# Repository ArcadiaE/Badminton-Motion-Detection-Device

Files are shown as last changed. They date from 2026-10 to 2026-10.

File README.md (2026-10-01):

# Wearable Device for Badminton Motion Detection

A wrist-worn device that recognises badminton strokes in real time and replies with coaching-style feedback. Built as my Part III individual project (undergraduate dissertation) at the University of Southampton, 2024–25. The full dissertation is in [`docs/Final_Report.pdf`](docs/Final_Report.pdf).

The device streams motion and physiological data over Bluetooth Low Energy. A support vector machine classifies four stroke types — forehand, backhand, slice and smash — at **77.37%** test accuracy (macro-averaged F1 = 0.76), up from 53.91% before the feature set was expanded from 10 to 16 dimensions. Given the single-IMU setup, four-class random guessing sits at 25%. Recognised strokes are passed to the ChatGPT API (GPT-4o), which generates personalised coaching feedback shown in a local Flask web app.

## Hardware

The electronics are packaged as a wristwatch with a 3D-printed case.

- **Microcontroller:** Arduino Nano 33 BLE Sense Rev2
- **IMU:** BMI270 + BMM150 (on-board, nine-axis)
- **Biosensor:** MAX30102 heart-rate and SpO2 module
- **Power:** 3.7 V 350 mAh LiPo battery, TP4056-based charging/management
- **Enclosure:** 3D-printed ([`3D_Model/3D.stl`](3D_Model/3D.stl), [`Enclosure/c1.stl`](Enclosure/c1.stl)); PCB layout in [`PCB/yuanlitu.brd`](PCB/yuanlitu.brd)

## Repository structure

- `Hardware/` — final embedded firmware (Arduino/C++): sensor initialisation, continuous sampling, filtering, differential and peak extraction, BLE broadcasting.
- `Data_Process/Matlab/` — MATLAB scripts for BLE data collection and CSV storage, plus the recorded sessions.
- `Data_Process/modelTrain/` — Jupyter-based SVM training, the trained models (`model/*.pkl`), the labelled stroke dataset (`BM_datas/`), and the Python inference script with the Flask feedback app (`templates/`).
- `Data_Process/python/` — earlier Python BLE capture prototype.
- `docs/` — the final dissertation.

## Dependencies

- **Arduino:** [ArduinoBLE](https://github.com/arduino-libraries/ArduinoBLE), [Arduino_BMI270_BMM150](https://github.com/arduino-libraries/Arduino_BMI270_BMM150), [SparkFun MAX3010x Sensor Library](https://github.com/sparkfun/SparkFun_MAX3010x_Sensor_Library), Madgwick.
- **MATLAB:** BLE toolbox (data collection).
- **Python 3.x:**
  ```bash
  pip install pandas scikit-learn joblib bleak flask openai
  ```

## Workflow

1. **Data acquisition** — the IMU streams tri-axial motion data over BLE; MATLAB scripts record sessions to CSV.
2. **Training** — the SVM is trained on the labelled dataset in a Jupyter notebook; the model, scaler and label encoder are exported with joblib.
3. **Inference** — a Python script receives live data and classifies the stroke with the trained model.
4. **Feedback** — the recognised stroke is sent to the ChatGPT API, and the generated coaching feedback is served in a Flask web interface.

## Author

**Yike Zhang**
School of Electronics and Computer Science, University of Southampton

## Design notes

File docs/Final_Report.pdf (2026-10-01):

# University of Southampton

# Faculty of Engineering and Physical Sciences

# School of Electronics and Computer Science

### Yike Zhang, yz50u22

### 21st April 2025

# Wearable Device for Badminton Motion Detection

### Project supervisor: Doctor Alex Weddell

### Examiner: Doctor Dimitra Georgiadou

### A project report submitted for the

### award of Beng Electrical and Electronic Engineering

### University of Southampton

### ABSTRACT

### FACULTY OF ENGINEERING AND PHYSICAL SCIENCES

### SCHOOL OF ELECTRONICS AND COMPUTER SCIENCE

By: Yike Zhang

Today, badminton motion analysis systems incorporating wearable sensors and machine learn-

ing models allow professional athletes to receive expert guidance more easily, while badminton

motion analysis systems incorporating wearable sensors and machine learning models have

enabled professional athletes to receive expert guidance more easily, existing systems often

remain too costly, bulky, or technically complex for amateur users, limiting their accessibil-

ity and daily usability. Amateur players would benefit more from a smaller, more convenient,

easier-to-understand, and more affordable wearable device. This project aims to design and

implement a wearable device focused on real-time detection of badminton stroke movements,

may facilitate improved access to expert-level guidance by replicating aspects of professional

systems in a more accessible form. The device can collect motion and physiological data,

which are transmitted to a mobile device for analysis via a Bluetooth Low Energy (BLE) mod-

ule. The project encompasses hardware design, data acquisition, signal processing, and the

development of machine learning-based action classification algorithms. The project has com-

pleted hardware coding, BLE communication initialisation, and filtering algorithm implemen-

tation. Beyond these technical completions, a functional prototype was successfully deployed

and tested in real-world scenarios with badminton club participants. The action classification

reached 77.37% accuracy for badminton strokes such as forehand, backhand, and smash. Ad-

ditionally, the system was able to generate real-time, personalised coaching feedback through

an integrated web interface using the ChatGPT API.

Statement of Originality

- I have read and understood the ECS Academic Integrity information and the University’s Academic Integrity Guidance for Students.
- I am aware that failure to act in accordance with the Regulations Governing Academic Integrity may lead to the imposition of penalties which, for the most serious cases, may include termination of programme.
- I consent to the University copying and distributing any or all of my work in any form and using third parties (who may be based outside the EU/EEA) to verify whether my work contains plagiarised material, and for quality assurance purposes.

I have acknowledged all sources, and identified any content taken from elsewhere.

I have acknowledged all sources in the report and clearly cited any content, figures, or ideas taken or adapted from external references.

I have used external resources.

The project uses the ArduinoBLE library by Arduino to implement Bluetooth Low Energy communication functions, and the SparkFun MAX3010x Sensor Library (version 1.0.5) for heart rate and SpO₂ signal acquisition and processing. Official Arduino tutorials for the Nano 33 BLE Sense Rev2 board and BLE device-to-device communication were referenced during sensor initialization and BLE service configuration. The OpenAI ChatGPT API (gpt-4o) was used to generate personalised coaching feedback based on recognised motion data. Additionally, Python libraries including pandas, scikit-learn, and joblib were used for machine learning model training, evaluation, and deployment, while the MATLAB BLE toolbox was employed for real-time data collection and CSV logging.

I did all the work myself, or with my allocated group, and have not helped anyone else.

I carried out all work myself, including hardware implementation, data acquisition, and software development, and did not help any other individual or group with their work.

The material in the report is genuine, and I have included all my data/code/designs.

The material in the report is genuine, and I have included all source code, raw and processed data, and hardware design information necessary to reproduce the results.

I have not submitted any part of this work for another assessment.

I confirm that no part of this work has been submitted for any other assessment, either within or outside the University

My work did not involve human participants, their cells, or animals; it only involved collecting motion data.

Approval was obtained from the University of Southampton Ethics and Research Governance committee (Reference Number: ERGO/FEPS/79094). All procedures were conducted following ethical guidelines, and informed consent was obtained from all participants.

## Contents

List of Figures | 6
List of Symbols | 7
1 Introduction | 8
2 Theoretical Background | 9
3 System Overview | 15
4 System Implementation | 20
5 System Testing, Performance, and Feedback | 27
6 Project Management | 35

7 Conclusion and Future Work | 38
Bibliography | 40
Appendix | 43
A Formulas | 43
B BLE UUID Table | 43
C Sensor Specifications | 44
D Ethics Approval Forms | 45
E Code Examples | 47

## List of Figures

1 | Example of Euler Angles reproduced from [11] | 13
2 | Overview of the Integrated Device | 17
3 | Software Architecture Overview | 19
4 | Code Implementation of I2C Scanner | 20
5 | Technical Drawing of Device Design | 23
6 | An earlier version of the design | 24
7 | When the device is initialised, the information printed by the Serial Monitor . . 28
8 | Outputs on Mobile APP LightBlue | 28
9 | An example of Collected Data | 29
10 | Training Evaluation of Trained Model of Simple Motions | 29
11 | When the device operates properly | 29
12 | Training outcome of the initial Algorithm | 30
13 | Training outcome of Final Algorithm | 31
14 | Code of API Testing Program | 32
15 | API Testing Outcome | 32
16 | UI of Localhost Website | 33
17 | Example of Forehand | 34
18 | Initial Gantt Chart | 36
19 | Fianl Gantt Chart | 37
20 | Pin layout of Arduino Nano 33 BLE Sense Rev2, reproduced form [9] | 44
21 | System Diagram of MAX30102, reproduced form [22] | 44
22 | Signed SOP Form | 45
23 | Ethics Approval Submissions | 45
24 | Ethics Application Form | 46
25 | Code example of Reading Data | 47
26 | Code example of Establish BLE Connection | 48
27 | Code example of Heartrate and SpO2 Algorithm | 48
28 | Peak Count Algorithm | 49
29 | The function for Connecting and Data Storage | 49
30 | Code example of Data Processing Progress in Pyhton | 50

31 | Code example of UI | 51
32 | Code example of Extended 16 Features | 52

## List of Symbols

IMU | Inertial Measurement Unit
Hz | Hertz (Unit of Frequency)
SpO2 | blood oxygen saturation

KNN K-Nearest Neighbor Algorithm

SV M | Support vector machine
BLE | Bluetooth low energy
ϕ | Roll (Used in this report)
θ | Pitch (Used in this report)
ψ | Yaw (Used in this report)

## 1. Introduction

### 1.1. Motivation

Modern professional badminton players can often benefit from the guidance provided by expert

coaches. With the integration of wearable sensors and machine learning technologies, advanced

badminton motion analysis systems are increasingly being adopted for training and gameplay.

However, for amateur badminton players, participating in periodic badminton courses offered

by clubs or other organisations often comes with challenges, such as the time it takes to partic-

ipate and the distances between home and clubs. Purchasing and using professional badminton

analysis systems can be expensive or overly complicated. So, designing a wearable device that

is cost-effective, portable, and user-friendly would enable users to effortlessly monitor their

performance data and receive personalised recommendations, helping them improve their tech-

niques. Furthermore, it enhances their enjoyment of the sport and reduces the risk of injuries

during play.

### 1.2. Project Objectives

The core objective of this project is to develop a wearable device and miniaturised device

based on a single sensor node for badminton stroke recognition, targeting amateur sports en-

thusiasts to enhance their real-time motion feedback and performance evaluation capabilities.

The system aims to capture users’ movement and physiological signals to recognize different

badminton strokes and provide real-time personalised feedback to amateur players. It is de-

signed to be lightweight, wearable, and capable of unobtrusive data acquisition during play.

Captured data should be processed efficiently to classify stroke types and generate actionable

improvement suggestions. The system must offer reliable operation, intuitive user interaction,

and the ability to support continuous skill development without needing professional supervi-

sion. Initially, data was collected from experienced badminton players through self-conducted

recording sessions to train a stroke classification model. Subsequently, when amateur bad-

minton players use the device, their real-time motion data will be compared against the trained

model. The comparison results will then be input into a large-scale artificial intelligence sys-

tem to generate personalized recommendations, with both the collected data and the generated

feedback visualized through platforms such as web interfaces.

### 1.3. Scope and Deliverables

This project covers hardware assembly, embedded development, data communication, web in-

terface construction, data acquisition programming, and data structure design. The system

components include the Arduino Nano 33 BLE Sense Rev2, the MAX30102 module, a 3D-

printed enclosure, and wearable mounting structures. The development work will be limited to

firmware-level sensor drivers, data acquisition programs, attitude estimation algorithms, BLE

characteristic configuration, a front-end display interface based on Flask, and MATLAB or

Python scripts for data reception and storage. The project deliverables include a functional pro-

totype of the sensor hardware, a set of host-side scripts supporting BLE interaction, a collection

of data samples for training classification models, and a basic web-based data visualisation in-

terface. The data collected during the project will be limited to the three-axis motion data of

the wrist. Physiological data collected by the MAX30102 will not be stored and will only serve

as a reference for users. All data collected in this project will be anonymous, containing no

identifiers that can link the data to individual participants, and the project has received ethical

approval from the Ethics Committee of the University of Southampton.

## 2. Theoretical Background

### 2.1. Motion Detection Techniques for Sports

### 2.1.1 Existing Projects

In sports motion analysis, wearable IMU(Inertial Measurement Unit) sensors have become a

prominent method for accurately identifying and classifying motion patterns. For instance,

Camomilla et al. [1]. During their research, they used IMU, which includes an accelerometer,

a gyroscope, and a Magnetic sensor, and analysed over 37 sports. They proved that the IMU

can be used to identify and classify sports. A particularly relevant study by Cutti et al. (2008)

proposed a calibration procedure for upper limb joint kinematics using wearable magnetic and

inertial measurement units based on bony landmark identification [2]. Similarly, Lebel et al.

(2018) applied wearable IMUs to running gait analysis, enhancing the understanding of biome-

chanics and the risk factors for injuries [3].

In badminton motion analysis, accurately identifying and classifying stroke actions is a critical

research area. Wang et al. (2016) proposed a method for badminton stroke recognition based

on Body Sensor Networks (BSNs) [4]. In their study, multiple IMU sensors were placed at

key locations on the athlete’s body, including the wrist, arm, and legs, to form a comprehen-

sive network for capturing motion data. Wang et al. adopted a multi-sensor setup to obtain

comprehensive motion data. While Camomilla et al. emphasized the broad applicability of

IMUs across sports, their work lacked domain-specific optimizations, limiting direct transfer-

ability to badminton. Cutti et al.’s approach offered precise limb joint calibration, but required

cumbersome wired systems unsuitable for mobile use. Lebel et al. focused on gait analy-

sis, which differs structurally from upper limb dynamics in racket sports. In contrast, Wang

et al.’s multi-sensor BSN system offered richer motion data but increased system complexity,

cost, and wearing discomfort. It should also be noted that Wang et al. evaluated the recogni-

tion performance of individual sensor nodes. Their results showed that the wrist sensor node

alone achieved the highest individual accuracy among the tested locations, reaching an aver-

age recognition accuracy of 81.63%. This suggests that, while a multi-node system enhances

overall robustness, a well-placed single sensor (such as on the dominant wrist) can still de-

liver relatively high accuracy, particularly when paired with appropriate signal processing and

feature extraction techniques.

### 2.1.2 Hardware Selections

In the study conducted by Cutti et al., a sensor named MT9B was employed, which comprised

a 3D accelerometer, a 3D gyroscope, and a 3D magnetometer, operating at a fixed sampling

rate of 100 Hz. This sensor required a wired connection to a computer and did not support

wireless transmission. In the study by Lebel et al., Attitude and Heading Reference Systems

(AHRS) were utilized to analyze motion performance, comparing systems such as the Xsens

MTx, APDM Opal, and Inertial Labs OSv3.

In the research by Wang et al., each sensor node comprised a triaxial accelerometer (ADXL326),

a single-axis gyroscope (LY550), and a biaxial gyroscope (LPR550). As these sensors lacked

integrated Bluetooth functionality, ZigBee modules were implemented to configure the sensor

nodes, and a wireless receiver module was connected to the computer for data acquisition.

In this project, the focus is on developing a miniaturized device based on a single sensor node;

therefore, sensor systems similar to those used by Cutti et al. and Lebel et al. will not be

considered. Instead, designs akin to that proposed by Wang et al., involving a microcontroller

with integrated Bluetooth functionality combined with an additional IMU module, are consid-

ered more appropriate. Several candidate solutions are summarized in Table 1. Among the

compared hardware options, professional-grade solutions like Xsens or Shimmer offer high

accuracy and sampling rates, but their prohibitive cost and setup complexity render them im-

practical for casual or amateur users. Raspberry Pi and ESP32 platforms offer programmability

and wireless communication but require additional IMU modules, increasing power consump-

tion and form factor, which may hinder integration in a wearable form. Arduino Nano 33 BLE

Sense Rev2, although limited in memory and requiring manual programming of BLE commu-

nication, provides a compact and integrated platform combining BLE and IMU in one unit.

This balance of cost, size, and functionality makes it the most suitable choice for this project’s

lightweight, wrist-mounted wearable application.

Option | Advantages | Disadvantages | Cost (£)
1. Raspberry Pi 4B + Ex-ternal IMU Module[6] | • User-friendly • Supports MicroPython and C/C++ programming. | • Requires an external sensor module, increasing size and power consumption. • Requires an additional wireless module. | • £60+
2. ESP32 Series De-velopment Board + Ex-ternal IMU Module[5] | • Built-in Wi-Fi and BLE. • Smaller size | • Also requires an external IMU module. • Higher power consump-tion; not conducive to portable sports equipment applications. | • £35+
3. Pro-fessional Sports Sensor Equip-ment (e.g., Xsens[7], Shimmer[8]) | • High precision and high sampling rate; professional-level motion capture performance. | • Expensive. For example, it costs C430 to purchase a Shimmer IMU unit. • Complex equipment. | • £370+
4. Arduino Nano 33 BLE Sense rev2[9] | • High Integration, the BLE and IMU modules are inte-grated on board. • Low Power Consumption. | • 256 KB of SRAM and 1 MB of flash limit the size of programs. • Relatively harder to pro-gram: i.e. Algorithms and BLE need to be established by programming. | • £50

Table 1: Comparison of Hardware Options

### 2.2. Attitude Estimation Algorithms

Attitude estimation involves determining an object’s orientation and rotational state in space. In

three-dimensional space, Euler angles can describe the orientation of a rigid body that requires

three independent angular parameters, which consist of roll (ϕ), pitch (θ), and yaw (ψ). Roll

refers to the rotation around the X-axis and represents the left or right tilt of the object. Pitch

refers to the rotation around the Y-axis and indicates the forward or backward tilt. Yaw refers

to the rotation around the Z-axis and describes the direction of the object within the horizontal

plane[10]. An example of Euler angles is shown in Fig.1.

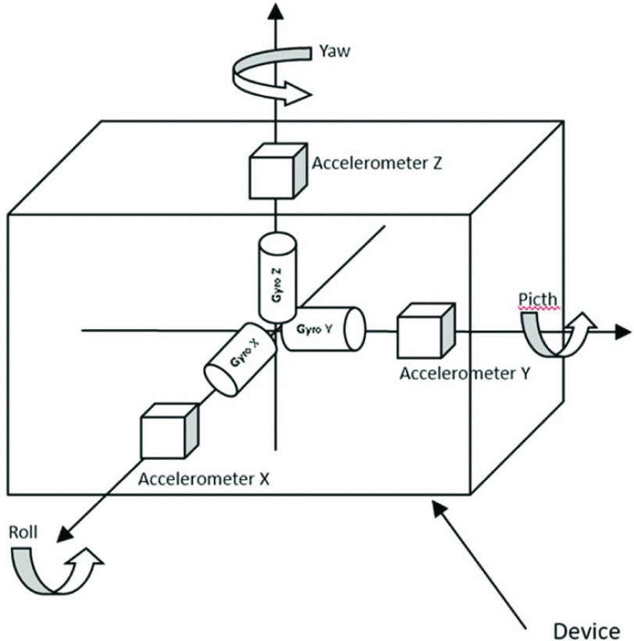
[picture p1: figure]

Figure 1: Example of Euler Angles reproduced from [11]

An accelerometer measures the gravitational components along each axis, from which the roll

and pitch angles can be calculated through geometric projection. A magnetometer measures

the horizontal components of the Earth’s magnetic field and can be used to estimate the yaw

angle (heading). A gyroscope measures the angular velocity around each axis, and the angular

displacement can be obtained through integration. The detailed derivation and implementation

of these calculations are provided in the Appendix, referencing the work of Sabatini (2006)

on attitude estimation using inertial sensors [12] and the summary by Noureldin et al. on yaw

angle estimation methods using magnetometers [13].

Each type of sensor within the IMU exhibits inherent limitations. For example, gyroscopes

suffer from drift errors during long-term integration; accelerometers show poor stability during dynamic movements; and magnetometers are vulnerable to disturbances from environmental

magnetic fields. To address these issues, a complementary filter is adopted in this project to

fuse data from the three sensors, leveraging the long-term stability of accelerometers and mag-

netometers and the short-term dynamic responsiveness of gyroscopes to generate smoother and

more stable attitude angle estimations. The filter design is based on the nonlinear comple-

mentary filter structure proposed by Mahony et al. [14], with specific weighting factors and

computational models detailed in the Appendix.

During data acquisition, the IMU is susceptible to external interferences, including involuntary

human tremors while wearing, mechanical vibrations during motion, and electromagnetic in-

terference (EMI) from the environment. Jankowski et al. conducted a systematic experimental

study on the sources of vibration-induced noise in MEMS accelerometers and identified the

inherent vibration of mechanical structures as one of the primary contributing factors [15]. Ca-

ballero et al. used electromagnetic tracking sensors to evaluate human movement variability

and demonstrated that natural tremors can significantly impact sensor accuracy [16]. Pahl et

al. validated the drift and nonlinear changes observed in gyroscopes and accelerometers when

subjected to electromagnetic interference [17].

To suppress high-frequency disturbances, a Butterworth low-pass filter is applied during the

data preprocessing stage. This filter features a flat frequency response within the passband and

effectively attenuates high-frequency noise without significantly distorting the main compo-

nents of the signal. The principles and characteristics of Butterworth filters were thoroughly

analysed by Butterworth in his seminal 1930 paper [18].

### 2.3. Motion Analysis Methods

In the study of motion analysis methods, Ghosh et al. proposed a comprehensive motion mod-

elling framework for table tennis stroke recognition. They developed a wearable sensor module

system by attaching an IMU to the wrist to capture tri-axial acceleration and angular velocity

signals. Statistical features such as mean, standard deviation, maximum, and minimum values

were extracted from each signal segment using a sliding window approach [19]. These features

were then input into a neural network model built using TensorFlow for classification training, followed by quantisation using TensorFlow Lite to adapt the model to the target hardware plat-

form. The motion analysis method adopted in this study constructed input vectors based on

local statistical features of IMU signals and employed a shallow neural network for multi-class

stroke action classification.

In existing studies on badminton motion recognition, machine learning methods have been

widely applied for IMU sensor-based data modelling tasks. Anik et al. proposed using sta-

tistical variations of orientation angle sequences as primary features, combined with stroke

duration and the position of the maximum acceleration point to construct feature vectors, util-

ising support vector machines (SVM) and k-nearest neighbours (k-NN) algorithms for action

classification [20]. SVM offers good generalisation capabilities and handles small-sample high-

dimensional spaces effectively. At the same time, k-NN is simple in structure and fast to imple-

ment, making it suitable for preliminary classification tasks under the real-time requirements

of wearable devices.

In addition to static feature modelling, some studies have introduced temporal structure mod-

elling methods. For instance, hidden Markov models (HMM) have been used to represent

action sequences as state paths, estimating stage transition probabilities based on observed se-

quences, which is suitable for recognising actions with sparse labels or continuous stages [4].

Building upon this, deep learning models such as long short-term memory networks (LSTM)

have been applied to modelling multi-phase swing processes in sports like badminton, leverag-

ing their capability to learn temporal dependencies for posture sequence classification. Seong

et al. employed an LSTM structure to process complete multi-phase stroke action sequences

and incorporated a bidirectional recurrent structure to introduce contextual information and en-

hance classification accuracy [21].

## 3. System Overview

### 3.1. Hardware Architecture

The system is custom-encapsulated in the form of a wristwatch and is worn on the user’s wrist.

The decision to use the wrist as the sensor placement site is based on two considerations. First, badminton stroke actions predominantly originate from wrist and arm movements, making the

wrist an ideal location to capture dynamic motion characteristics. Second, prior studies such

as Wang et al. (2016) reported that wrist-mounted sensors achieved the highest single-node

recognition accuracy among various body positions. The internal structure integrates the main

control board, sensors, battery, and charging management module. At the same time, the exter-

nal casing is fabricated through lightweight 3D printing to ensure mechanical stability and user

comfort during physical activities. The system’s core control unit is the Arduino Nano 33 BLE

Sense Rev2, featuring an nRF52840 Bluetooth chip that supports the BLE 5.0 communication

protocol. It transmits attitude feature data streams to the host computer via custom-defined

service and characteristic UUIDs. The Arduino board is integrated with the LSM9DS1 nine-

axis inertial measurement unit (IMU), capable of real-time acquisition of tri-axial acceleration,

angular velocity, and magnetic field data. A complementary filter is employed to compute the

raw sensor outputs’ roll, pitch, and yaw attitude angles. After filtering and differential process-

ing of the sensor data, the firmware periodically transmits the results to the computer via BLE

broadcasting, enabling real-time data acquisition and analysis.

The bottom of the system is equipped with a MAX30102 biosensor module for measuring

the user’s heart rate and blood oxygen saturation. This sensor utilises photoplethysmography

(PPG) to output SpO2 and pulse rate data, with direct skin contact to improve signal quality. It

should be noted that the physiological parameters collected by the MAX30102 are not involved

in subsequent motion recognition or machine learning model inputs; they are provided solely

for users’ reference to monitor their physical status after training sessions or competitions and

are not utilised in system recognition logic or algorithmic inference.

Power is supplied by a 3.7v, 350mAh rechargeable LiPo battery. To ensure sufficient operating

time for typical training sessions and data collection activities, the system was designed with

a target battery life of at least 10 hours. Based on the measured average current consumption

of approximately 25 mA by the sensors and main board during operation, a 3.7V, 350mAh

rechargeable LiPo battery was selected. This configuration enables continuous operation for

approximately 11.7 hours. The battery management module is based on the TP4056 chip,

providing overvoltage, overcurrent, and thermal protection features, and supporting automatic

USB power switching and safe charging. Overall, the hardware system offers strong portability and energy efficiency, meeting the basic requirements for battery life, stability, and real-time

data transmission in wearable sports monitoring applications. The figure2 shows an overview

of the integrated device.

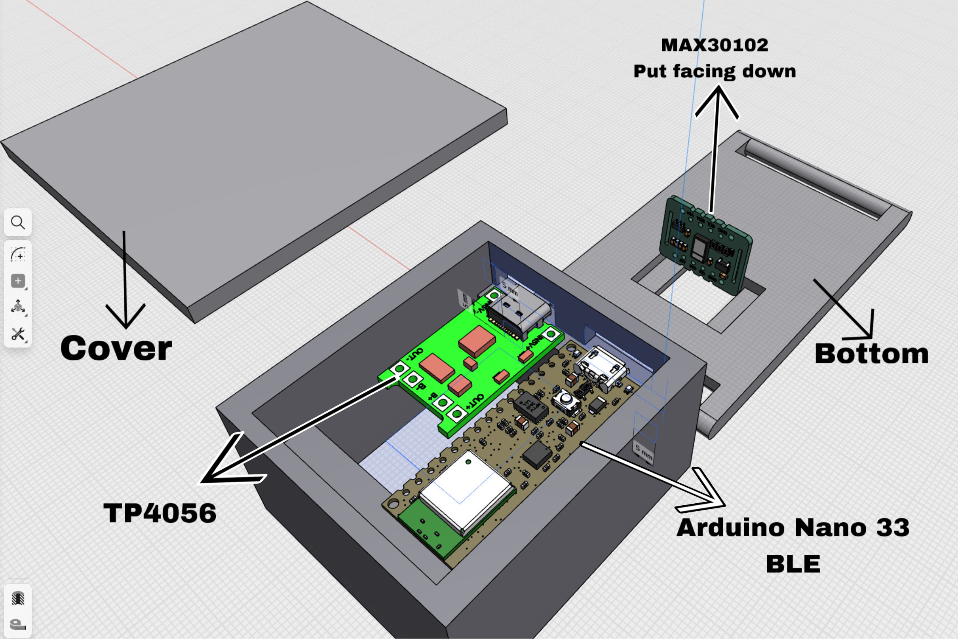
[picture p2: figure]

Figure 2: Overview of the Integrated Device

### 3.2. Software Architecture

The software system has two main components: the embedded control and host-side data anal-

ysis programs. The embedded program is developed in C++ based on the Arduino framework

and is primarily responsible for sensor initialisation, continuous sampling, data filtering, differ-

ential computation, peak extraction, and BLE broadcasting.

The host-side program is implemented using a combination of MATLAB and Python. The

system reads the broadcasted attitude angle data via Bluetooth in the MATLAB scripts. The

retrieved data are processed within the script to compute angular velocity and angular accel-

eration, and the results are stored in CSV files with timestamp formatting. These files are

subsequently used for machine learning model training.

The trained model is then applied for motion recognition, comparison, and recommendation

generation, which is implemented through Python scripts. The Python scripts, based on the

pandas and scikit-learn frameworks, are responsible for reading the data, preprocessing fea-

tures, loading the trained models, and outputting classification results. A local visualisation and feedback system is developed using Flask, enabling the visualisation of the collected data,

model training results, and personalised recommendations through a web interface.

### 3.3. Data Flow and System Workflow

The system operates in two stages. The first stage is data collection, during which motion

data from professional badminton players and coach volunteers performing different types of

strokes are collected to serve as standard reference templates. During this stage, the IMU con-

tinuously reads tri-axial motion data and transmits it to the computer, where it is stored as CSV

files. Machine learning model training is conducted based on this dataset. The training process

is performed in Jupyter Notebook, and a support vector machine (SVM) is employed as the

classification model for this project.

The second stage is motion recognition and feedback. When users wear the device and perform

badminton strokes, their motion data is transmitted to the computer via BLE. A Python script

receives the incoming data and applies the previously trained model to recognise which type

of stroke the user has performed. The recognised action is then compared with the standard

stroke templates stored in the model. The Python script is also integrated with the ChatGPT

API, allowing the comparison results to be passed to ChatGPT for generating personalised

feedback aimed at helping users improve their performance. An overview of software archi-

tecture is shown in Fig.3. The diagram illustrates the complete software architecture, showing

the interaction between the embedded firmware, host-side programs, and external services.

It distinguishes between two operational stages: MATLAB-based data collection and model

training, and Python-based real-time inference and feedback. Official libraries were used in

software design, and the self-written code was used to implement the functions.

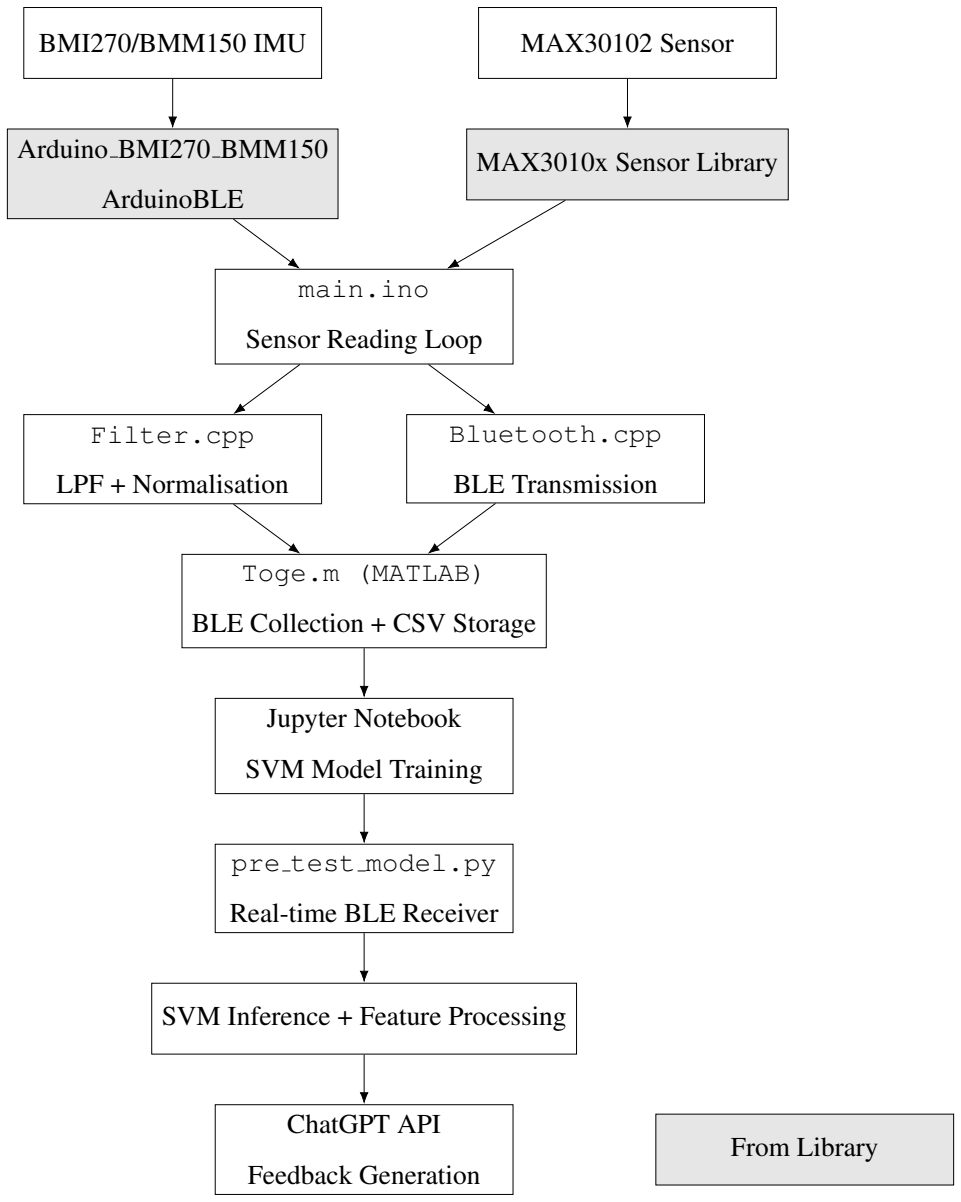
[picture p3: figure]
BMI270/BMM150 IMU; MAX30102 Sensor; Arduino BMI270 BMM150; ArduinoBLE; MAX3010x Sensor Library; main.ino; Sensor Reading Loop; Filter.cpp; LPF + Normalisation; Bluetooth.cpp; BLE Transmission; Toge.m (MATLAB); BLE Collection + CSV Storage; Jupyter Notebook; SVM Model Training; pre test model.py; Real-time BLE Receiver; SVM Inference + Feature Processing; ChatGPT API; Feedback Generation; From Library

Written Code

Figure 3: Software Architecture Overview

## 4. System Implementation

### 4.1. Seneor Implementation

The main control program completes serial port initialisation and device identification for the

IMU and MAX30102 sensors within the setup() function. Using the I2C protocol, the system

performs address scanning to verify peripheral connection status 4. During the sensor initial-

isation process, error detection mechanisms are incorporated. If a device fails to respond, an

exception is reported via the serial port, and a timeout strategy is executed to ensure fault tol-

erance in the subsequent data acquisition workflow.

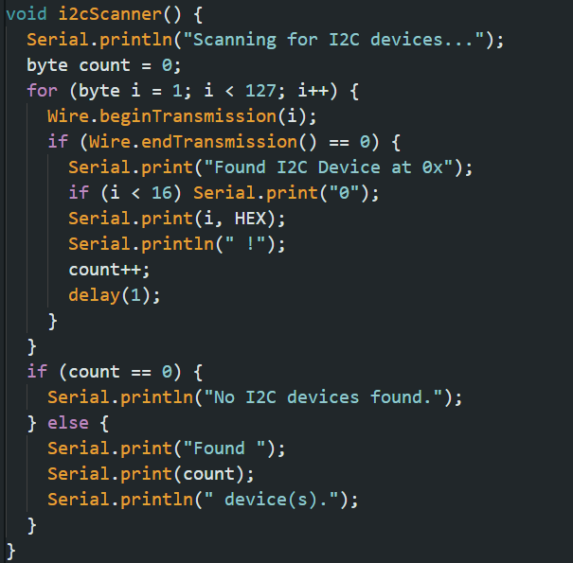
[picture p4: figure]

Figure 4: Code Implementation of I2C Scanner

The sensor hardware code is developed using official Arduino libraries[9]. The official Ar-

duino tutorials[25] were consulted to learn how to use these libraries and their functions, but no

tutorial code was directly reused. During inertial measurement data processing, the program

acquires tri-axial raw data from the BMI270 accelerometer, gyroscope, and the BMM150 mag-

netometer. It then applies the imuLowPassFilter() function to perform exponential first-order

low-pass filtering on the acceleration, angular velocity, and magnetic field intensity. Filtering

parameters are defined as global variables, allowing adjustments to the filter coefficient to con-

trol the trade-off between response sensitivity and noise suppression. The filtered nine-axis

data are subsequently fed into the attitude estimation algorithm, where roll, pitch, and yaw

angles are individually computed. Roll and pitch are calculated using the arctangent function based on acceleration components, while yaw is derived from the horizontal components of the

magnetic field.

The program employs a complementary filter structure to fuse the gyroscope integration results

with the sensor-derived angle estimates, independently updating the three attitude angles. The

computed results are normalised and stored in global variables for use by the BLE interface.

The angle computation process is controlled by timed sampling to maintain consistent integra-

tion steps, ensuring accurate conversion from angular velocity to angular displacement over

real-time evolution.

Heart rate and blood oxygen saturation measurements are carried out using the MAX30102

sensor module[22]. The system configures the sensor in SpO2 operating mode, with a sam-

pling rate set to 100 Hz, an ADC range of 16384 nA. These parameters were selected based

on the trade-off between signal quality and power consumption. A sampling rate of 100 Hz

ensures sufficient temporal resolution to capture typical pulse waveforms without excessive

computational load. The ADC range of 16384 nA provides adequate sensitivity for physiolog-

ical signals while preventing saturation under moderate LED currents. The LED current was

set to 60 (approx. 12 mA) to balance signal intensity and skin comfort, based on manufacturer

recommendations and empirical testing on different skin tones. The program invokes the up-

date() method from a custom HeartRateSpO2 class during each main loop iteration to read red

and infrared signals from the sensor and buffer them internally. Pulse wave envelope detection

and signal decomposition algorithms are then executed to extract peak-to-peak intervals and

light intensity variations per sampling cycle, from which heart rate (in BPM) and blood oxygen

saturation (percentage) are calculated. The results are returned to the main program as floating-

point values and assigned to global variables for BLE transmission and serial output.

Bluetooth communication functionality is implemented using the ArduinoBLE library[26]. A

custom service UUID is configured during initialisation, and independent characteristic chan-

nels are registered for roll, pitch, yaw, heart rate, and SpO2 measurements. After starting the

BLE service, the device enters advertising mode, awaiting a central device connection. Upon

successful connection, the program checks the BLE connection status in each main loop iter-

ation; if connected, it invokes the updateBLECharacteristics() function to package and write the latest sensor data to the respective characteristics, ensuring that connected devices receive

motion and physiological signals at a near real-time frequency (approximately 100 Hz). The

characteristics are transmitted in 32-bit floating-point format to ensure compatibility with main-

stream BLE clients and low-latency decoding. To prevent resource conflicts, BLE data updates

are prioritized over serial output, providing stable and continuous Bluetooth data transmission.

Serial debugging output is integrated into the main loop via the printSensorData() function.

This function categorically prints the attitude angles and physiological parameters, allowing

real-time monitoring of all metrics during the development phase. The output follows a fixed

format, facilitating automatic parsing by serial reading programs and logging systems. Sam-

pling interval control is applied during output to maintain synchronization with BLE updates,

preventing data lag and buffer overflow issues.

### 4.2. Mechanical Design

The system’s casing is designed to be a sports wrist-worn device, requiring compact volume,

stable wearing, and a reasonable distribution of sensor exposure areas. The main body of the

device measures 30×51×56 mm, with the longest point reaching 79 mm including the strap

connection. These dimensions were determined primarily to accommodate all hardware com-

ponents, while also taking into account ergonomic requirements during wrist movement. The

device adopts a two-layer design: the upper layer houses the Arduino board and the charging

module. Positioning the Arduino on the upper layer ensures that the physical thickness of the

device does not obstruct Bluetooth signal transmission. Two USB openings are reserved: one

for Arduino program uploading and the other for battery charging. These openings are sym-

metrically placed on the rear face of the upper shell, as shown in Fig. 5.

The lower layer serves as the battery compartment and accommodates the MAX30102 biosen-

sor. A 17×14 mm opening is reserved at the bottom of the device to expose the sensor’s photodi-

ode and LED emitter window, enabling direct optical contact with the user’s skin and ensuring

reliable signal acquisition. This opening was dimensioned to match the active sensing region

of the module and was refined through empirical testing. The casing is fabricated using 3D

printing, and the full design schematic is provided in Fig. 5. The device is worn using a soft,

adjustable wristband fixed through a hollowed-out side structure. The overall mass is approximately 30 grams, which avoids a significant load sensation during prolonged use.

The final casing design is the result of multiple iterations. An earlier prototype featured a sim-

ilar layout but failed to account for the vertical clearance required by the Arduino board’s pin

headers, which made proper installation impossible. Additionally, the wristband attachment

openings were initially too narrow to accommodate standard strap connectors. As shown in

Fig.6, the upper side of the figure shows that the wristband attachment opening is designed

to be 0.5 mm, which is ideally enough for a wristband’s thickness, but didn’t consider the 3D

printing error. And the height of that design is 14.5 mm, which increased to 30 mm in the

final design. The lower side of the figure showed that if Arduino was installed on the device, it

would be higher than the coverage of the case. To resolve these issues, the casing dimensions

were increased in the final version, providing sufficient height for internal components and en-

suring compatibility with adjustable wristbands. Bluetooth signal performance and mechanical

stability also improved as a result of the revised layout.

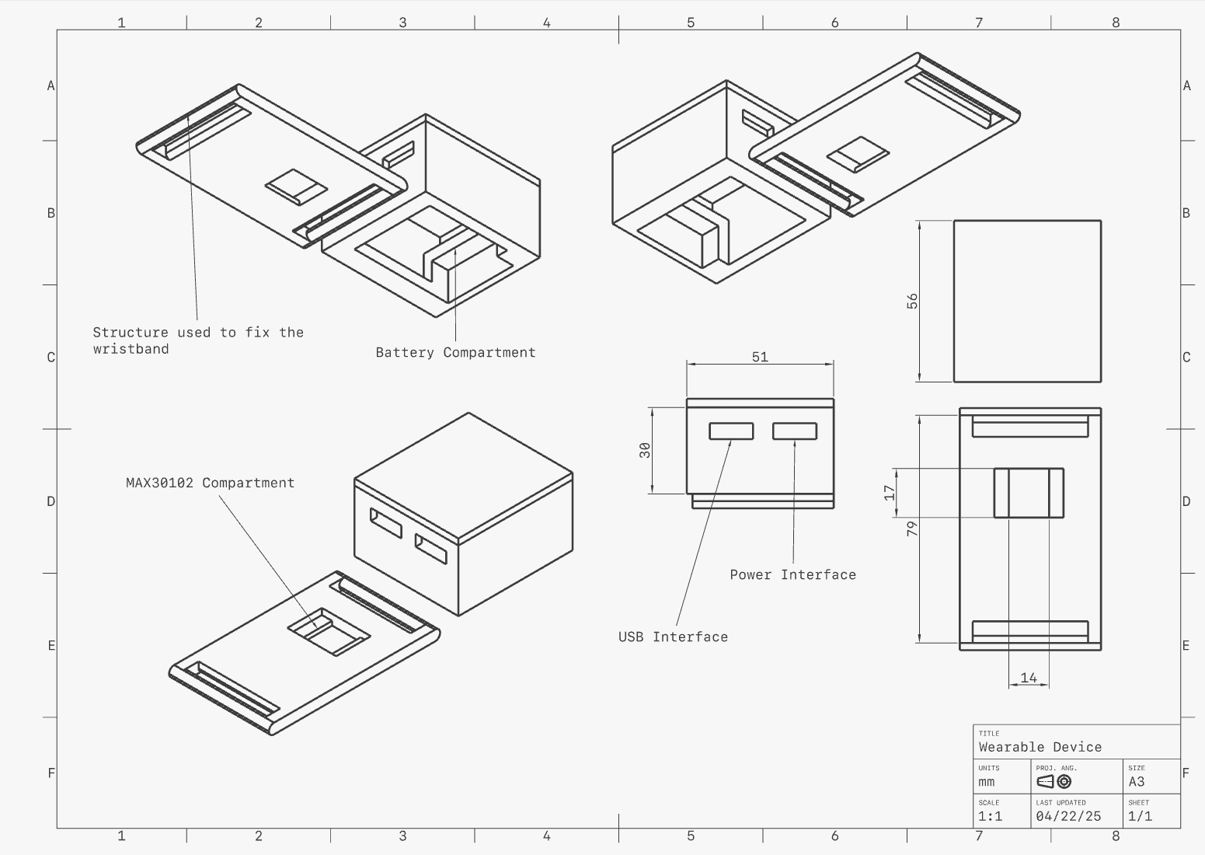
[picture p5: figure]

Figure 5: Technical Drawing of Device Design

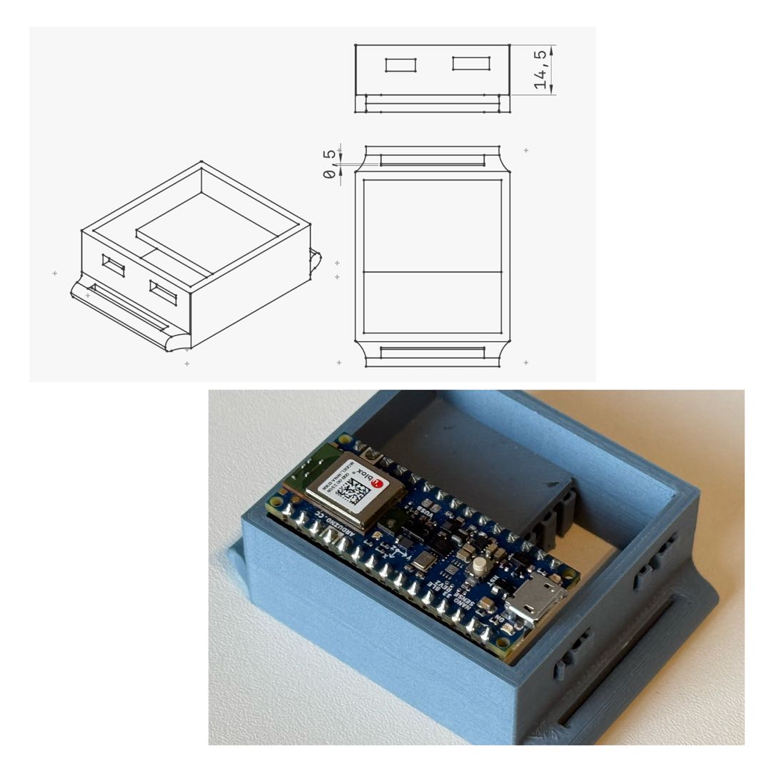
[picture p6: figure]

Figure 6: An earlier version of the design

### 4.3. Machine Learning-Based Action Classification

The training data were collected using the MATLAB script. The script searches for Bluetooth

devices using blelist and connects to the target device. It continuously reads five raw features:

roll, pitch, yaw, heartRate, and SpO2. To construct temporal features, the script calculates

the angular velocities of roll, pitch, and yaw at each sampling instance by differencing the

current and previous values, and further differencing yields angular accelerations. The angular

velocity of the roll axis is buffered in a sliding array, and the number of extremum points is

computed through second-order sign differencing within the window to obtain the peak count

(peak count). pseudocode 1 shows the peak count algorithm implemented in Matlab. These

seven features are combined to form a feature vector, and after each sampling cycle, the vector,

along with the timestamp and the five raw features, is saved into a CSV file in real time, the

pseudocode 2 below shows the function connect to the Arduino and store the data into a csv

file. Users manually append action labels as target variables for supervised learning.

Algorithm 1: Peak Counting Algorithm Input: 1D array of numeric values data

Output: Number of peaks peakCount

### 1 if length of data ¡ 3 then

2 peakCount ← 0;

### 3 else

4 Compute first-order differences: ∆1 ← diff(data);

5 Compute signs of ∆1: s ← sign(∆1);

6 Compute second-order difference: ∆2 ← diff(s);

### 7 Count negative transitions in ∆2:

8 peakCount ← number of elements where ∆2 < 0;

### 9 end

Algorithm 2: BLE Connection and Data Logging Procedure Input: Target device name

Output: CSV file with sensor data and derived features

1 Generate timestamped CSV filename;

2 Open file for writing, write CSV header;

3 Scan for BLE devices, locate target by name;

### 4 if target not found then

5 Display error and exit;

6 Connect to device address with retries;

### 7 if connection fails then

8 Display error and exit;

9 Bind characteristic UUIDs for roll, pitch, yaw, heart rate, SpO2;

10 Initialize buffers for time and data arrays;

### 11 while program not interrupted do

12 Read raw sensor values from each characteristic;

13 Compute velocities and accelerations via differencing;

14 Count motion peaks from velocity buffer;

15 Write timestamp and all features to CSV file;

### 16 end

The machine learning model training is conducted in Jupyter Notebook. The training script uses pandas to load the collected and labeled CSV files. Labels are cleaned using .str.strip(),

and effective action labels (‘push’, ‘rest’, ‘swing’, ‘rolling’) are selected. The input fea-

tures include roll velocity, pitch velocity, yaw velocity, roll acceleration, pitch acceleration,

yaw acceleration, and peak count. Labels are encoded into integers using LabelEncoder. The

dataset is split into training and testing sets with an 8:2 ratio, and features are normalized

using StandardScaler. The model is initialised using SVC(kernel=’rbf’) and trained by call-

ing .fit() on the training set. During testing, predictions are generated using .predict(), and

performance metrics are reported using classification report() and accuracy score(). After

training, the model (pre svm model.pkl), the scaler (pre scaler.pkl), and the label encoder

(pre label encoder.pkl) are saved to the local directory using joblib.dump(), for use by the in-

ference script.

Support Vector Machine (SVM) was chosen as the final classification model based on the fol-

lowing considerations. First, the amount of data collected in this project is limited, and the

number of motion samples is insufficient to support the data-intensive requirements of deep

learning models such as LSTM or Transformer architectures. Among traditional shallow mod-

els, k-nearest neighbours (k-NN) offers simplicity and interpretability but requires traversing

the entire training set during inference, making it unsuitable for real-time response demands

in the web feedback system. Random Forest exhibits some robustness but tends to overfit and

produce unstable prediction boundaries when feature dimensionality is low and class distri-

bution is imbalanced. In contrast, SVM demonstrates significant advantages in small-sample,

high-dimensional classification tasks, offering high post-training accuracy and short inference

times, making it suitable for integration with web interfaces for real-time prediction.

The inference and feedback system is implemented through the Python script pre test model.py.

The script uses BleakScanner.discover() to automatically scan and connect to the Bluetooth

device. After establishing the GATT service, it reads the real-time data corresponding to each

feature UUID. In each sampling cycle, the script computes angular velocities between two con-

secutive frames of roll, pitch, and yaw, calculates angular accelerations based on velocity dif-

ferences, and performs extremum point counting using a sliding window over the roll velocity

signal to obtain the peak count. The constructed feature vector is normalized using the pre-

loaded scaler, following the same feature order as during training, and then fed into the pretrained SVM model for action prediction. The predicted label is decoded back into text using

the label encoder.

After prediction, the system invokes openai.ChatCompletion.create(), passing the

recognized action category as a prompt to the GPT-4o API. As I’ve mentioned in chapter 3.3,

note that no raw sensor data or personal information is sent to the GPT API; only the predicted

class label is included in the prompt. The model is requested to generate technical evaluations

and personalised advice in the style of a professional coach. The generated suggestion, current

action, and real-time data are packaged into a dictionary object and output as JSON data via

the Flask endpoint sensor data.

The front-end visualization is built based on the Flask framework. The web page template uses

the HTML file, rendered via render template() and loaded as the homepage under the route.

The browser periodically requests the sensor data endpoint to retrieve real-time JSON data and

dynamically displays the page’s current attitude derivatives, inferred action label, and textual

advice. Upon system startup, the web service listens on local port 5000, allowing users to

access localhost:5000 via a browser to view the recognised stroke type and corresponding im-

provement suggestions.

## 5. System Testing, Performance, and Feedback

The program was first uploaded to the Arduino board during the initial testing phase and pow-

ered through a USB connection to the computer. Upon powering on, the device status could be

monitored via the Serial Monitor in the Arduino IDE. If the system operated correctly, the Se-

rial Monitor would display readings as shown in the Fig.7. At this point, Bluetooth initialisation

would be complete, and the device would start broadcasting to the surrounding area. Using the

mobile application LightBlue, the device could be successfully connected, and various sensor

parameters could be observed, verifying that device initialisation, Bluetooth communication,

and basic data reading were functioning correctly8. However, it should be noted that at this

stage, it was not yet possible to conclude whether the sensor readings accurately reflected real

motion states, requiring further validation.

Figure 7: When the device is initialised,
the information printed by the Serial Mon-
itor | Figure 8: Outputs on Mobile APP Light-
| Blue

The next step was integration testing. The device was mounted onto a breadboard via pins,

and the MAX30102 sensor was connected to the Arduino’s I²C interface (A4, A5) and power

interface (3V3, GND) via wires. The device connection status was first verified using the pre-

configured I²C Scanner functionality in the firmware. If operating normally, the Serial Monitor

displayed outputs as shown, and the LED on the MAX30102 module lit up. After confirm-

ing basic hardware functionality, preparation was made to connect the battery for testing. The

project used a 350mAh LiPo battery, with a fully charged voltage of approximately 4.2V, drop-

ping to around 3.2V when near depletion. By measuring the battery voltage to ensure it was

within the usable range, the battery was connected to the TP4056 input, and the TP4056 output

was wired to the Arduino power input pin, providing additional stability protection through the

TP4056’s overvoltage, overcurrent, and thermal safeguards.

After these preliminary tests, initial accuracy testing was conducted by connecting the Blue-

tooth device via a custom MATLAB script. For this step, the tester held the device and per-

formed three types of motions: waving, arm rotation, and front-back swinging. Each action

was repeated across multiple sets, with each set lasting approximately two minutes. Labs were

manually appended after collecting sufficient motion data, and a labelled dataset was created

as shown in the Fig.9. This data was then used to train an initial model. The evaluation results

of the trained model10 showed an overall accuracy of 88.95% and a macro-averaged F1-score

of 0.90, indicating good classification performance. Among the categories, the rolling action

achieved the best classification results, with a Precision of 1.00 and an F1-score of 0.98, exhibit-

ing almost no misclassifications. The push and rest actions also demonstrated high accuracy and recall. However, the swing action exhibited a relatively lower Recall of 0.72, suggest-

ing that some swing samples were misclassified, indicating a need for further optimisation of

feature extraction or class balance. Overall, the model showed stable and strong recognition

capabilities across most action classes, making it a solid foundation for subsequent motion

recognition systems.

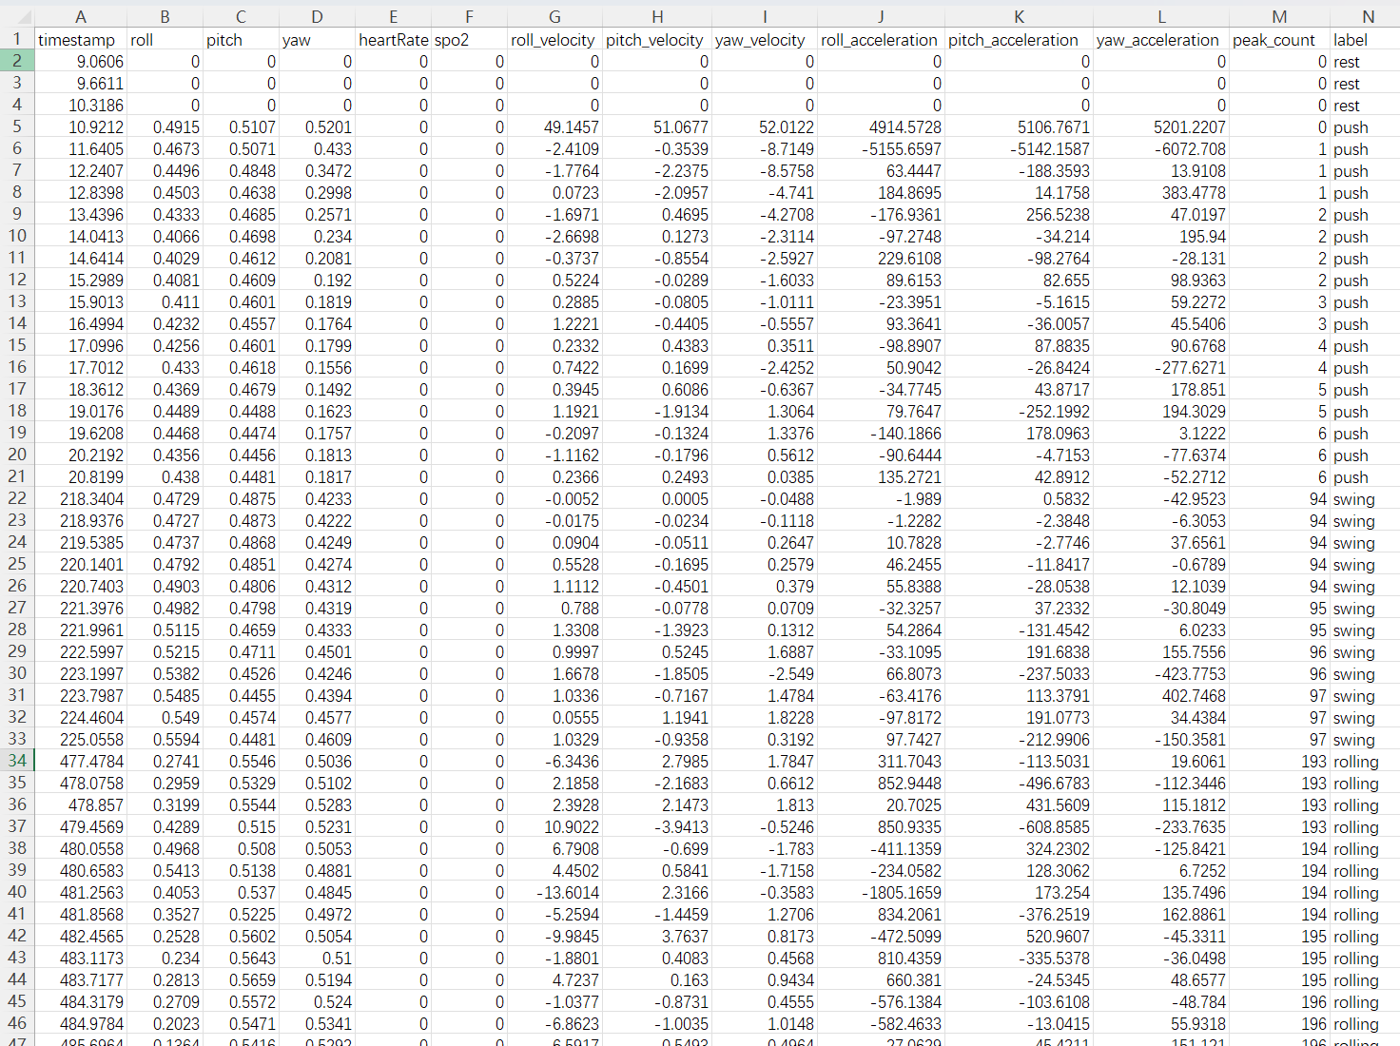
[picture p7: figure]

Figure 9: An example of Collected Data

Figure 10: Training Evaluation of Trained Model of Simple Motions

Before testing the fully assembled system, a standalone debug program, debug.py, was devel-

oped to ensure Python could successfully establish Bluetooth communication and display data

on the Flask web interface. Running independently of the server framework, this script used

the Bleak library to connect to the device and read each Bluetooth characteristic value sequen-

tially. After each read, the script displayed both the floating-point value of each characteristic

and the underlying raw byte stream, facilitating detection of data parsing errors or anomalies.

During actual debugging, it was observed that data updates refreshed every 0.5 seconds, and

the vast majority of data was correctly parsed. Occasionally, when the sensor experienced a

momentary disconnection or Bluetooth interference, the script accurately captured and output

error messages. As shown in the Fig.11, the device can operate normally.

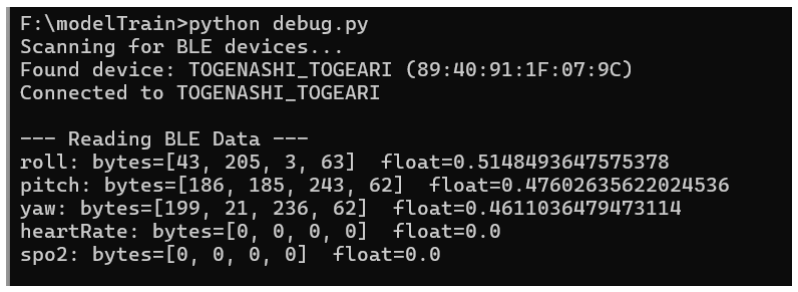
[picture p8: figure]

Figure 11: When the device operates properly

After the completion of device assembly, collaboration was established with the University of

Southampton Badminton Club (RecBad) to conduct device testing and data collection, with

the assistance of two club members. After the participants wore the device and connected

it via Bluetooth to a computer, they performed stroke actions. Four types of strokes were

tested: Forehand, Backhand, Forehand Slice, and Smash. Multiple sets of each stroke type

were recorded, with each set lasting approximately 2–5 minutes. Breaks were provided when

participants experienced fatigue. After collecting sufficient data, a badminton motion detection

model was trained using the acquired badminton stroke dataset.

The initial classification performance evaluation results are shown in the Fig.13 following the

preliminary training of the model using the badminton stroke data. The support vector machine

(SVM) model, constructed based on basic features such as angular velocity, angular accelera-

tion, and peak count, exhibited relatively poor recognition performance. The test set accuracy

was only 53.91%, and the macro-averaged F1-score was 0.50. Specifically, although the Back-

hand action showed a relatively high recall, its precision was low, indicating many misclassifi-

cations. While the Forehand action exhibited relatively good precision, it suffered from a high

rate of missed detections. Recognition performance for the Forehand Slice and Smash actions

was generally low, particularly for the Smash action, where the F1-score was only 0.34. These

results indicate that the initially selected feature set was insufficient to adequately represent the

dynamic characteristics of different stroke types, resulting in blurred classification boundaries

and limited model performance.

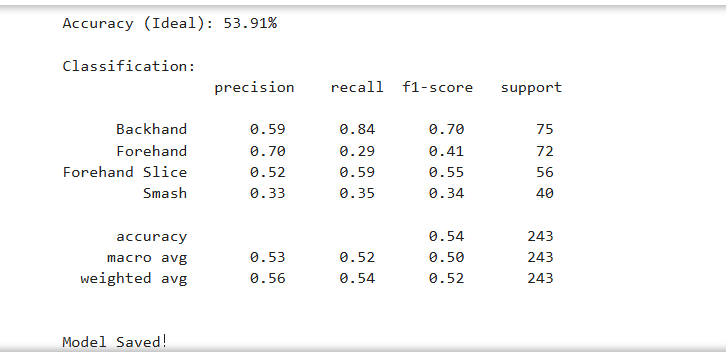
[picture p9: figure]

Figure 12: Training outcome of the initial Algorithm

To address this issue, a systematic feature expansion was conducted. In addition to retaining

the original features, information regarding the absolute spatial position of actions was introduced. Furthermore, the absolute values of angular velocity and angular acceleration along

each axis were calculated to enhance sensitivity to motion amplitude variations and reduce the

directional noise’s impact. After the feature expansion, the input dimensionality increased from

10 to 16, effectively enriching the motion feature space. After the improvements, the retrained

SVM model exhibited a significant performance enhancement. On the test set, the overall ac-

curacy increased to 77.37%, and the macro-averaged F1-score improved to 0.76. Recognition

performance across different action classes also became more balanced, with the Backhand

action achieving an F1-score of 0.84, Forehand at 0.75, Forehand Slice at 0.79, and Smash

at 0.64. As discussed in the background section, previous systems employing multiple IMUs

or multi-sensor arrays have typically achieved classification accuracies of 85–90%. However,

such systems rely on complex multi-point deployments and are less constrained by portability.

In contrast, this system uses only a single wrist-mounted IMU under real-time and ergonomic

limitations. For a four-class task, random guessing yields 25% accuracy, and simple heuris-

tics, such as threshold-based peak detection, fixed value segmentation, or manually defined

acceleration angle rules, these classification relies on manually set cutoffs rather than learning

discriminative features. These approaches rarely exceed 50–60%. Therefore, under the current

hardware constraints, the achieved 77.37% accuracy is acceptable.

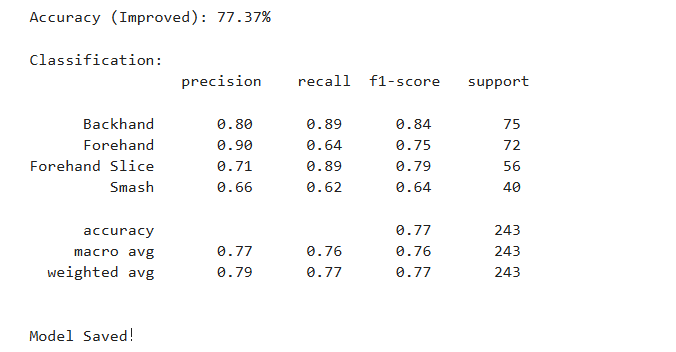
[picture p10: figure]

Figure 13: Training outcome of Final Algorithm

To ensure that the system could reliably generate motion analysis and personalized suggestions,

an independent test script, api testing.py, was developed14. This script directly calls the

OpenAI ChatGPT API to verify the API key’s validity and the server connection’s stability. By

sending fixed test prompts and reading the returned messages, the API endpoint was confirmed

to be responsive and capable of stably generating textual feedback. The successful API call results are shown in the Fig.15.

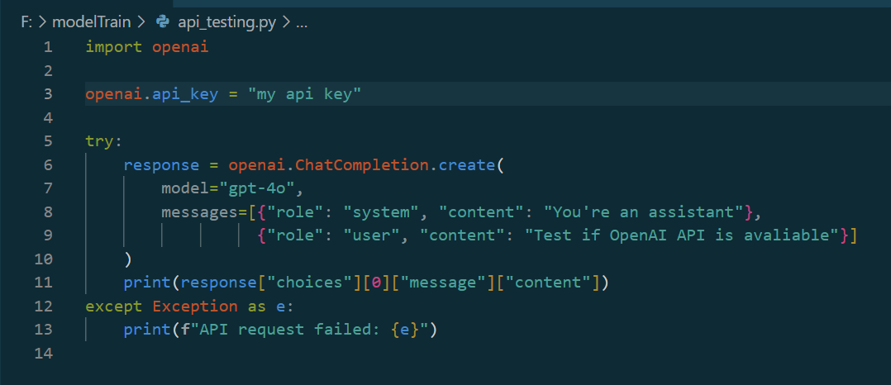
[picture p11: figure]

Figure 14: Code of API Testing Program

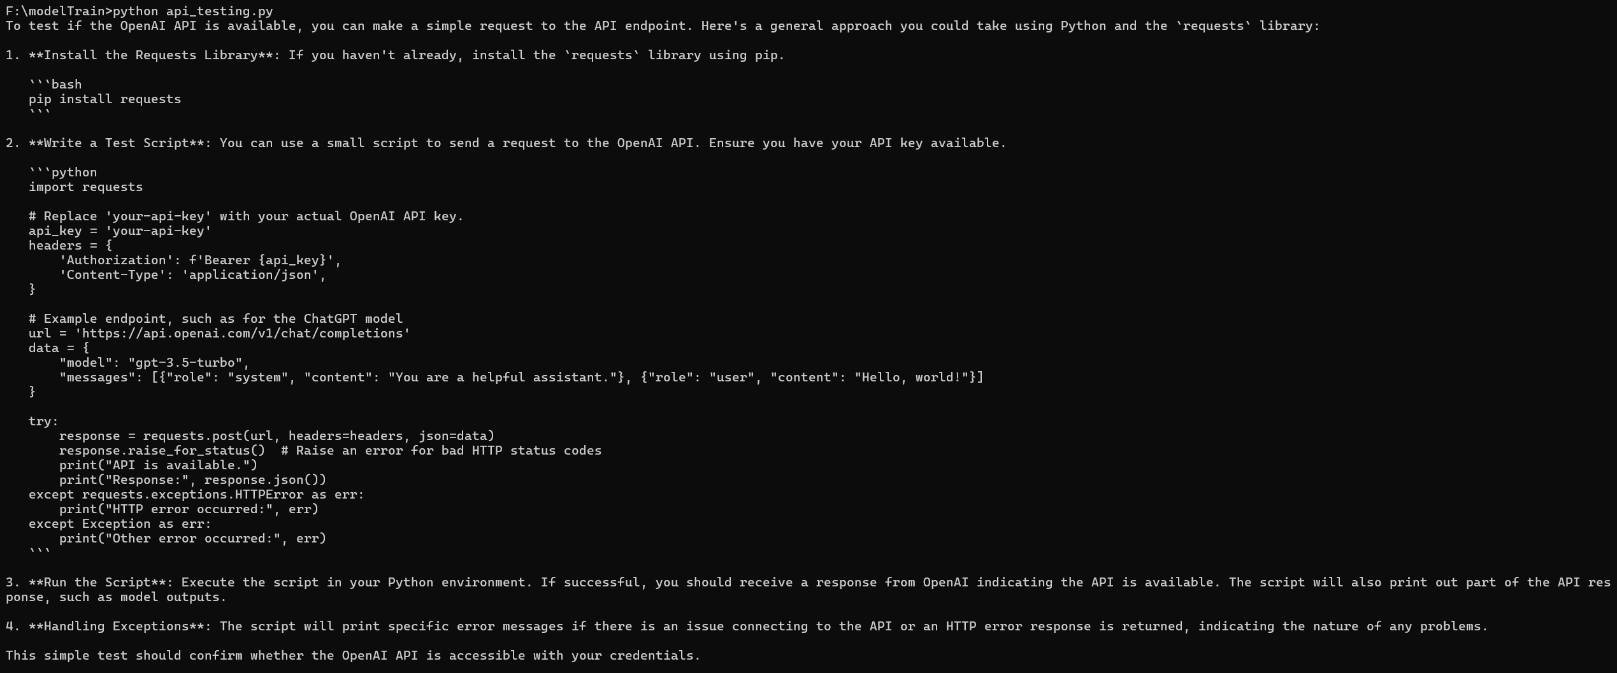
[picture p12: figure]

Figure 15: API Testing Outcome

After completing system integration, a full round of testing based on real motion data was

conducted using custom Python scripts. A participant wore the device on the wrist, which was

connected to the computer via Bluetooth. The system continuously recorded the changes in roll,

pitch, and yaw angles during movement, along with corresponding angular velocities, angular

accelerations, absolute angular velocities, absolute accelerations, and peak counts, resulting

in a total of sixteen sensor features. The data were uploaded in real time at an approximate

frequency of once every 0.5 seconds and were simultaneously refreshed on the web interface.

By accessing http://localhost:5000/, as shown in Fig.16, the webpage displayed

two main sections: Sensor Data and Prediction. The Sensor Data module listed the real-time

changes of each feature in detail. The interface responded smoothly, and the variations of all

indicators were consistent and continuous.

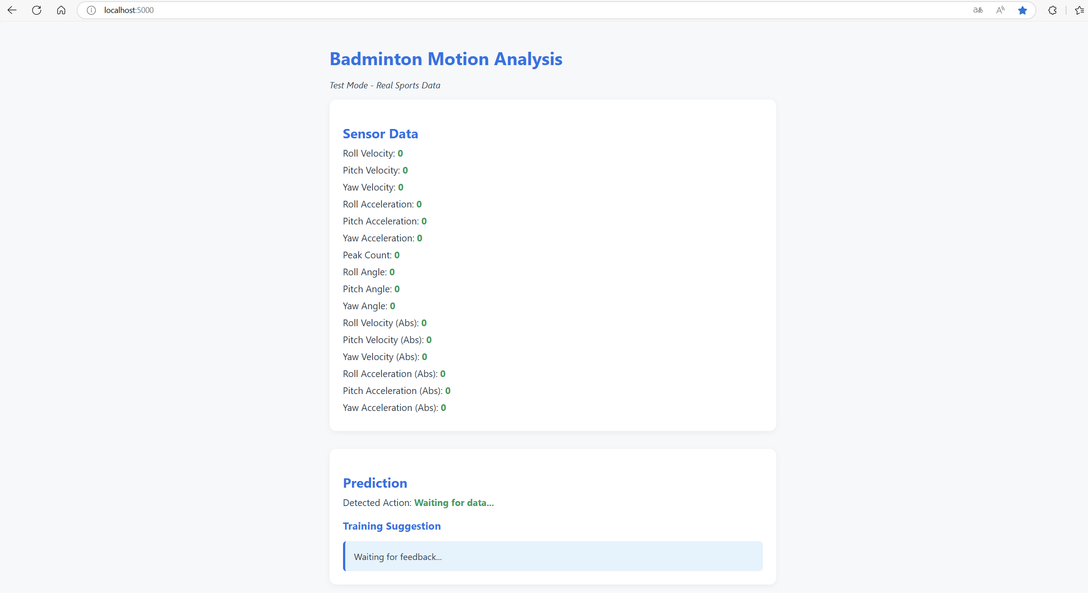
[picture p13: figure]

Figure 16: UI of Localhost Website

As shown in Fig.17, taking the Forehand action as an example, the system could classify the

action shortly after completion and generate detailed, personalised training advice. During

the stance phase, players should position their feet shoulder-width apart, with the front foot

slightly forward and the rear foot turned outward, shifting the centre of gravity onto the ball

of the front foot. The spine should be naturally extended with a forward lean of 15°–20°,

and the shoulders should remain relaxed and lowered. In the preparation phase, the racket

arm’s elbow should be slightly above shoulder level, forming a 90° elbow angle, with the

racket head positioned behind the hand and pointing upwards to establish a loaded posture. To

correct issues such as insufficient backswing or low elbow position, mirror practice or video

playback was recommended. During the execution phase, players should drive the arm forward

naturally from the shoulder, adding a controlled wrist snap at impact for power generation.

The contact point should be 30–45 cm in front of and slightly to the right of the body, with

a vertical racket face for accurate direction; if too close to the body, footwork drills were

suggested. In the follow-through phase, the racket head should extend naturally forward and

upward, with the elbow opening slightly outward and the racket head kept above the wrist

to maintain motion continuity. Additional advice included using simulated targets to regulate

the swing trajectory and timers to build rhythm, ensuring smooth transitions across all phases.

Daily practice routines such as 20 sets of Shadow Drill swings (each over 60 seconds) combined

with fixed-position Multi-feed drills were also recommended to improve consistency.

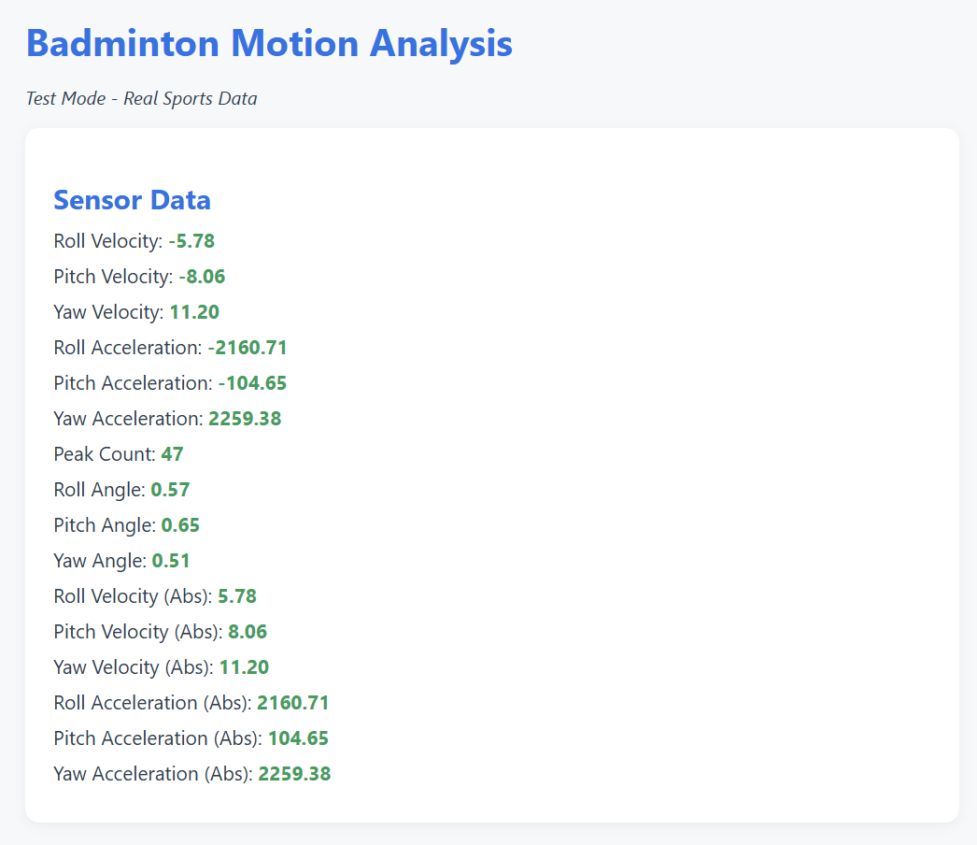
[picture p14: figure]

Figure 17: Example of Forehand

Participants also provided concrete suggestions for improving the device’s wearing experience

during testing. Most participants reported that the bottom structure of the device was insuf-

ficiently contoured to match the natural curvature of the human forearm. The current design

did not fully account for the physiological arch formed by the natural bend of the forearm,

leading to incomplete contact between the device and the skin. During large-amplitude move-

ments such as swinging and body rotation, localised pressure increased, particularly on the

wrist’s dorsal side and the forearm’s proximal region, causing discomfort. Additionally, some

participants pointed out that the device’s overall weight was relatively high. Although this did

not significantly affect short-term use, during prolonged multi-session exercise tests, the accu-

mulated weight increased the load on the arm muscles, leading to the early onset of fatigue,

especially after performing high-frequency swinging actions. Some participants noted that

compared to training without additional weight, wearing the current device version made the

forearm muscles more prone to early fatigue and reduced the fluidity of movements towards the

later stages of the testing session. Based on this feedback, participants generally recommended

that future versions should optimise the curvature of the device’s contact surface to better con-

form to ergonomic curves of the arm, and further reduce the overall device weight to minimise

interference with natural motion patterns, thereby improving comfort and naturalness during

prolonged wearing.

## 6. Project Management

### 6.1. Project Time Management

At the beginning of the project, a Gantt Chart was drawn as shown in the Fig18. Before the

project commenced, based on the project objectives, the overall development process was bro-

ken down into specific subtasks, arranged sequentially according to their completion order,

with the required duration for each subtask clearly estimated. The work was initially divided

into six major phases: hardware development, embedded programming, data collection, ma-

chine learning training, system integration, final testing, and report writing. Within each phase,

detailed tasks were further specified. In the initial estimation, it was assumed that software

development would consume more time. However, once the hardware programming was com-

pleted, data collection could be initiated simultaneously with the development of the machine

learning models and the Flask-based local server, thus saving time through parallelisation.

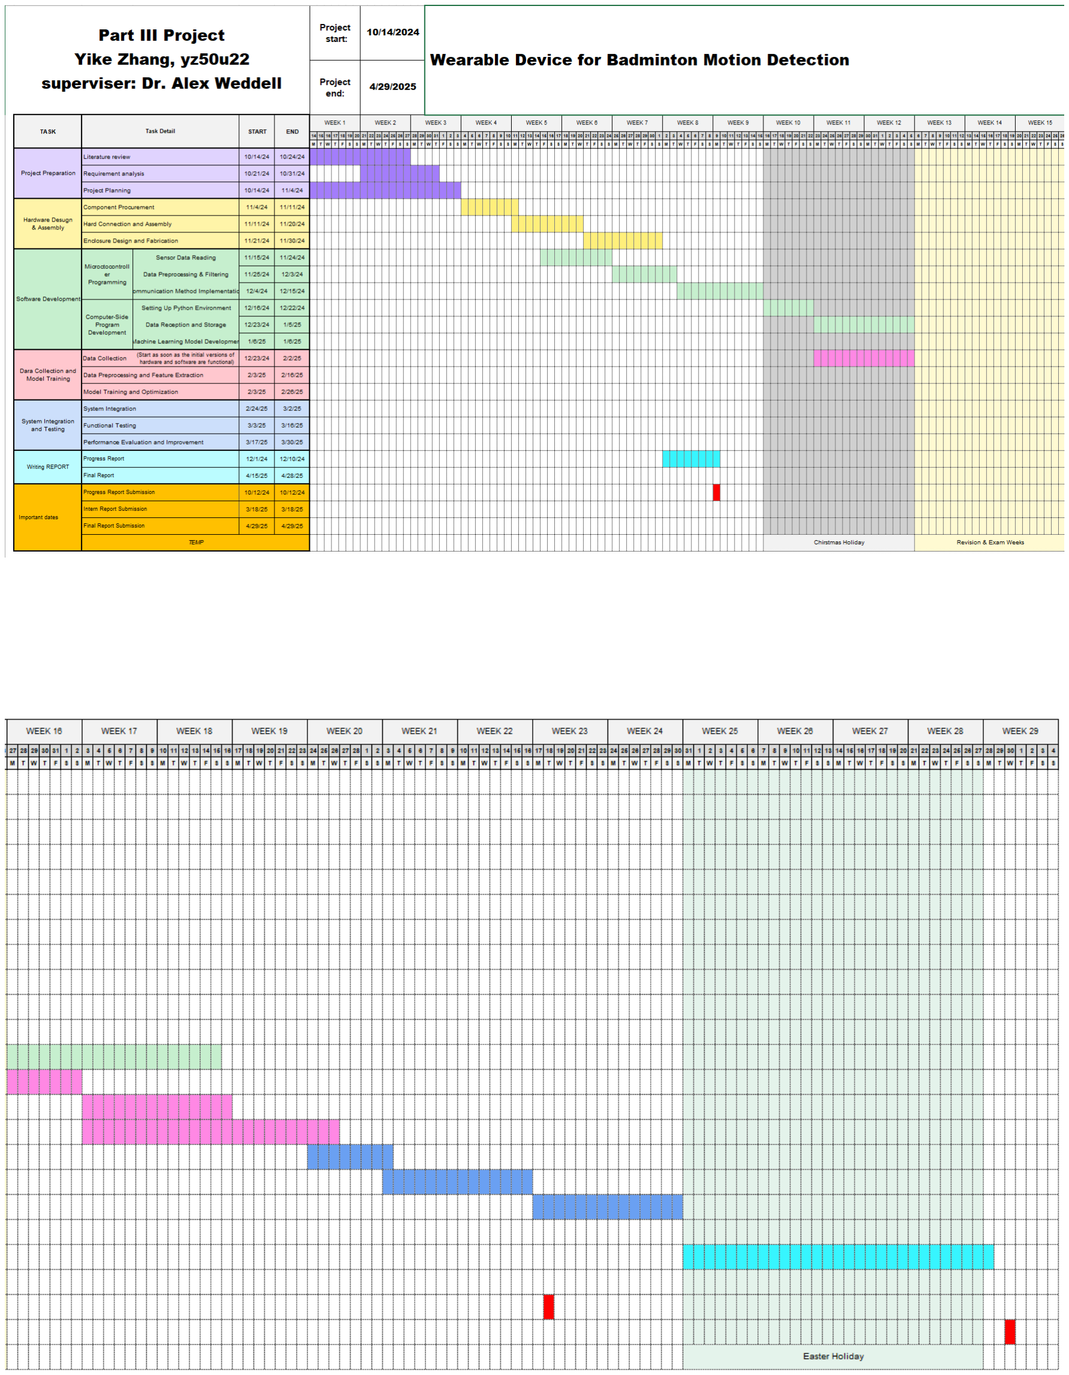
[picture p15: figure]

Figure 18: Initial Gantt Chart

Nevertheless, during actual implementation, difficulties encountered during the development

of the Bluetooth communication module delayed data acquisition, as the inability to correctly

read sensor data prevented the start of data collection. This resulted in a postponement of the

hardware testing phase. Furthermore, toward the end of the project, an additional delay oc-

curred when the Arduino board was damaged due to a short circuit. As no backup hardware

was prepared, integration testing and further data collection were also delayed. Throughout the

project execution, it was also observed that some time estimations made during the planning

phase were inaccurate. For instance, data collection and system testing were found to pro-

ceed simultaneously rather than sequentially, as initially planned. Based on the actual project progress and outcomes, an updated Final Gantt Chart was produced, as shown in the Fig.19.

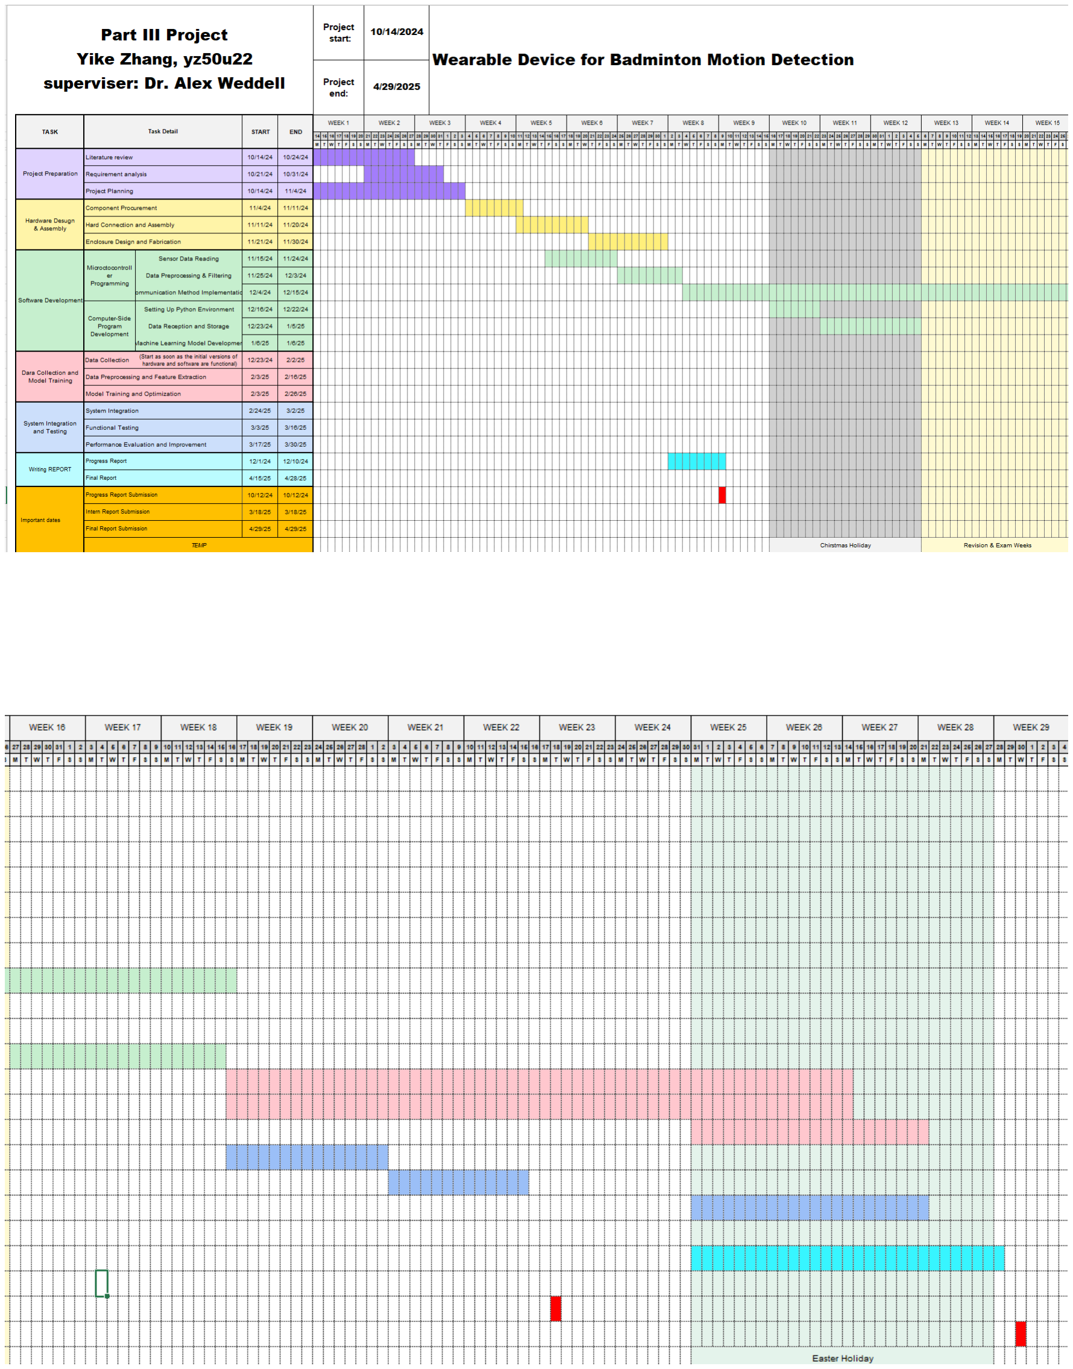
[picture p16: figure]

Figure 19: Fianl Gantt Chart

### 6.2. Project Risk Management

Since this project involves designing a wearable sensor and collecting data from participants,

ethical approval from the University of Southampton Ethics Committee was required. This

project’s data are strictly limited to arm motion data, heart rate, and blood oxygen saturation.

No personally identifiable information (i.e., data that can be linked to an individual’s identity)

will be collected, and all data will remain anonymous. Although participants may be asked to complete a Consent Form, the consent forms will not be associated with the collected data.

Additionally, participants retain the right to withdraw from the study at any time without con-

sequence. Copies of the Ethics Application Form and the Consent Form are included in the

Appendix of this report.

## 7. Conclusion and Future Work

### 7.1. Summary of Achievement

This project successfully developed a wearable badminton motion detection device based on

the Arduino Nano 33 BLE Sense Rev2 platform. The system can reliably collect IMU data

along with heart rate and blood oxygen saturation data. After applying filtering processes, stan-

dardized attitude angles are extracted. Using the BLE (Bluetooth Low Energy) module, both

motion and physiological data are transmitted in real-time to mobile devices. Furthermore,

through machine learning model training, the system is able to provide users with personalized

feedback and suggestions.

During testing, the participant completed the four types of badminton strokes included in the

experimental sample set without a predefined action sequence. During the motion, the roll-

direction angular acceleration rapidly increased to nearly +2000 within a short period, while

the yaw-direction acceleration exhibited peak values exceeding +2200. The roll angular veloc-

ity reached a high peak of approximately +15 at the initial stage of the action and then quickly

reversed direction, generating a typical dynamic signature characteristic of stroke actions. Si-

multaneously, the web interface recorded a significant increase in the peak count value during

the action cycle, reaching between 45 and 50, indicating that the rapid directional changes

during the motion were effectively captured. The roll, pitch, and yaw angle data exhibited a

continuous and smooth variation trend throughout the action, without sudden spikes or data

loss, demonstrating the stability of the system’s data acquisition chain.

Upon completion of each action, the system performed motion recognition based on the sixteen

real-time collected features. It updated the detected action category in the Prediction section

of the web interface. During testing, the system successfully recognised actions using the real-

time sensor data and promptly displayed the updated recognition results on the web interface.

### 7.2. Limitations

Reflecting on the project, several limitations were identified. During testing, heart rate detection

exhibited inevitable fluctuations and inaccuracies, particularly during intense physical activi-

ties, where signal stability declined, resulting in abnormally low or discontinuous heart rate

readings. Blood oxygen saturation measurements performed well under resting conditions but

showed reduced reliability during active movement. Using a single sensor node to monitor mo-

tion also presents inherent limitations. Although most actions could be recognised, in practical

scenarios, minor differences between specific actions, or action deformations caused by factors

such as fatigue, introduced inaccuracies into the data, leading to potential misclassifications.

Additionally, although the action recognition model performed well on the collected dataset,

the sample size remains relatively small. The clarity of the decision boundaries between action

classes is limited, introducing a risk to the model’s generalisation capability. While the web in-

terface has been functionally completed, systematic optimisation for data synchronisation and

page response efficiency under high-concurrency conditions has not yet been conducted.

### 7.3. Future Works

Further research on badminton motion detection and personalised feedback systems will be

pursued in the future. It is intended to explore the use of multi-sensor systems by integrating

lightweight, miniaturised sensors at key joint locations, connected to the main device through

IoT technologies, to enhance motion data accuracy. Advanced algorithms will be introduced

into sensor data processing to reduce attitude drift errors further. The motion recognition mod-

ule will be expanded by increasing the dataset size, collecting samples from users of various

skill levels and a wider variety of detailed action types to enhance model robustness and gener-

alisation performance.

The web interface will be enhanced on the software side by adding modules for real-time train-

ing feedback, historical record management, and motion trend analysis. Development of a dedi-

cated mobile application may also be considered. Future exploration could include multi-modal

sensor fusion (e.g., combining electromyography, EMG, signals) to recognise more complex

motion states. Further optimisation of device power consumption and battery life will also be

pursued to support long-term monitoring during extended training sessions.

## Bibliography

1. Camomilla, V., Bergamini, E., Fantozzi, S., & Vannozzi, G. (2018). Trends supporting

the in-field use of wearable inertial sensors for sport performance evaluation: A system-

atic review. Sensors, 18(3), 873.

2. Cutti, A. G., Giovanardi, A., Rocchi, L., Davalli, A., & Sacchetti, R. (2008). Upper limb

joint kinematics using wearable magnetic and inertial measurement units: An anatomi-

cal calibration procedure based on bony landmark identification. Medical & Biological

Engineering & Computing, 46(2), 169–178.s

3. Lebel, K., Boissy, P., & Hamel, M. (2018). Inertial measures of motion for clinical

biomechanics: Comparative assessment of accuracy under controlled conditions—Current

state and perspectives. Sensors, 18(2), 609.

4. Wang, Z., Guo, M., & Zhao, C. (2016). ”Badminton Stroke Recognition Based on Body

Sensor Networks,” IEEE Transactions on Human-Machine Systems, vol. 46, no. 5, pp.

769–775, Oct. 2016, doi: 10.1109/THMS.2016.2571265.

5. Espressif Systems. Development boards. Retrieved from https://www.espressif.

com/en/products/devkits (https://www.espressif.com/en/products/devkits) [Accessed: 1 Dec 2024].

6. Raspberry Pi Foundation. Raspberry Pi 4 Model B specifications. Retrieved from https:

//www.raspberrypi.com/products/raspberry-pi-4-model-b [Accessed:

1 Dec 2024].

7. Movella. Xsens sensor modules. Retrieved from https://www.movella.com/

products/sensor-modules (https://www.movella.com/products/sensor-modules) [Accessed: 7 Dec 2024].

8. Shimmer Sensing. Wearable sensor products: Individual sensors. Retrieved from https:

//shimmersensing.com/wearable-sensor-products [Accessed: 1 Dec 2024].

9. Arduino. (2024). ”Nano 33 BLE Sense Rev2: Technical Specifications.” Arduino Doc-

umentation. Available at: https://docs.arduino.cc/hardware/nano-33-

ble-sense-rev2/#tech-specs. (https://docs.arduino.cc/hardware/nano-33-ble-sense-rev2/#tech-specs) Accessed on: 1st December 2024.

10. Craig, J. J. (2005). Introduction to Robotics: Mechanics and ControlPearson Prentice

Hall.

11. Petrov, P. L. (2023). IMU Sensor Fusion with Quaternion Interval-Based Orientation

Filters Processed over Smartphone Scanned Data. XXXII International Scientific Con-

ference Electronics (ET), Sozopol, Bulgaria, 1-5. Available at: https://doi.org/

10.1109/ET59121.2023.1027976 (https://doi.org/10.1109/ET59121.2023.1027976)

12. Sabatini, A. M. (2006). Quaternion-based strap-down integration method for applications

of inertial sensing to gait analysis. Medical & Biological Engineering & Computing,

44(1-2), 101–109.

13. Noureldin, A., Karamat, T. B., & Georgy, J. (2013). Fundamentals of Inertial Naviga-

tion, Satellite-based Positioning and their Integration, Chapter 3: ”Magnetometer-based

Techniques”, pp. 87-92. Springer, New York, NY.

14. Mahony, R., Hamel, T., & Pflimlin, J.-M. (2008). Nonlinear Complementary Filters

on the Special Orthogonal Group. IEEE Transactions on Automatic Control, 53(5),

1203–1218.

15. Jankowski, M.; Szermer, M.; Zajac, P.; Amrozik, P.; Maj, C.; Nazdrowicz, J.; Jabłonski, ´

G.; Sako9wicz, B. An Experimental Investigation of Noise Sources’ Contribution in the

Multi-Chip Module Open-Loop Comb-Drive Capacitive MEMS Accelerometer. Elec-

tronics 2024, 13, 2599. https://doi.org/10.3390/electronics13132599

16. Caballero, C.; Barbado, D.; Moreno, F.J. Human Motor Noise Assessed by Electromag-

netic Sensors and Its Relationship with the Degrees of Freedom Involved in Movement

Control. Sensors 2023, 23, 2256. https://doi.org/10.3390/s23042256

17. Pahl, A.; Rathjen, K.-U.; Dickmann, S. Intended Electromagnetic Interference with Mo-

tion Detectors. 2021 IEEE International Joint EMC/SI/PI and EMC Europe Symposium,

Raleigh, NC, USA, 2021, pp. 324-328. https://doi.org/10.1109/EMC/SI/

PI/EMCEurope52599.2021.9559187 (https://doi.org/10.1109/EMC/SI/PI/EMCEurope52599.2021.9559187)

18. Butterworth, S. (1930). On the Theory of Filter Amplifiers. Wireless Engineer, 7(6),

536-541.

19. Ghosh, S., Gholap, Y., & Tallur, S. (2023). Wearable sensing module for Table Tennis

stroke detection. In Proceedings of the 2023 IEEE Applied Sensing Conference (AP-

SCON) (pp. 1–3). doi: https://doi.org/10.1109/APSCON56343.2023.

10101257 (https://doi.org/10.1109/APSCON56343.2023.10101257)

20. Anik, M. A. I., Hassan, M., Mahmud, H., & Hasan, M. K. (2016). Activity recognition

of a badminton game through accelerometer and gyroscope. In Proceedings of the 2016

19th International Conference on Computer and Information Technology (ICCIT) (pp.

213–217). doi:10.1109/ICCITECHN.2016.7860197

21. Seong, M., Kim, G., Yeo, D., & others. (2024). MultiSenseBadminton: Wearable Sen-

sor–Based Biomechanical Dataset for Evaluation of Badminton Performance. Scientific

Data, 11, 343. https://doi.org/10.1038/s41597-024-03144-z

22. MAXIM Integrated. (2017). MAX30102 Pulse Oximeter and Heart Rate Sensor Module.

Datasheet. Retrieved from: https://datasheets.maximintegrated.com/

en/ds/MAX30102.pdf (https://datasheets.maximintegrated.com/en/ds/MAX30102.pdf)

23. SparkFun. (2024). SparkFun MAX3010x Sensor Library. GitHub Repository. Avail-

able at: https://github.com/sparkfun/SparkFun_MAX3010x_Sensor_

Library (https://github.com/sparkfun/SparkFun_MAX3010x_Sensor_Library)

24. SparkFun Tutorials. (2024). MAX30102 Pulse Oximetry and Heart Rate Sensor Hookup

Guide. Available at: https://learn.sparkfun.com/tutorials/max30102-

pulse-oximetry-and-heart-rate-sensor-hookup-guide (https://learn.sparkfun.com/tutorials/max30102-pulse-oximetry-and-heart-rate-sensor-hookup-guide)

25. Arduino Documentation. ”Arduino Nano 33 BLE Sense Rev2 Tutorials”. Available

at: https://docs.arduino.cc/hardware/nano-33-ble-sense-rev2/

#tutorials. (https://docs.arduino.cc/hardware/nano-33-ble-sense-rev2/#tutorials)

26. Arduino Documentation. ”BLE Device-to-Device Communication Tutorial”. Available

at: https://docs.arduino.cc/tutorials/nano-33-ble-sense-rev2/

ble-device-to-device. (https://docs.arduino.cc/tutorials/nano-33-ble-sense-rev2/ble-device-to-device)

27. ”Bluetooth Smart or Version 4.0+ of the Bluetooth specification”. bluetooth.com. Archived

from the original on 10 March 2017.

28. University of Southampton, University of Southampton Health & Safety Risk Assessment:

General ECS Teaching Lab Risk Assessment, 2024. Available at: https://secure.

ecs.soton.ac.uk/notes/ellabs (https://secure.ecs.soton.ac.uk/notes/ellabs) [Accessed December 1, 2024].

## Appendix

## A. Formulas

The Formulas used to calculate the Eular Angles used in the project.

ϕacc = arctan 2(ay, az) | (1)

θacc = arctan
p

−ax
a

2
y + a

2
z

!
(2)
ψacc = arctan 2(my, mx) | (3)

ϕgyro = ωx∆t

θgyro = ωy∆t

ψgyro = ωz∆t

(4)

## B. BLE UUID Table

This appendix lists the BLE services and eigenvalue UUIDs used by the device:

service/features | UUID
Service UUID Roll Pitch Yaw Heart Rate SpO2 | 19B10000-E8F2-537E-4F6C-D104768A1214 19B10001-E8F2-537E-4F6C-D104768A1214 19B10002-E8F2-537E-4F6C-D104768A1214 19B10003-E8F2-537E-4F6C-D104768A1214 19B10004-E8F2-537E-4F6C-D104768A1214 19B10005-E8F2-537E-4F6C-D104768A1214

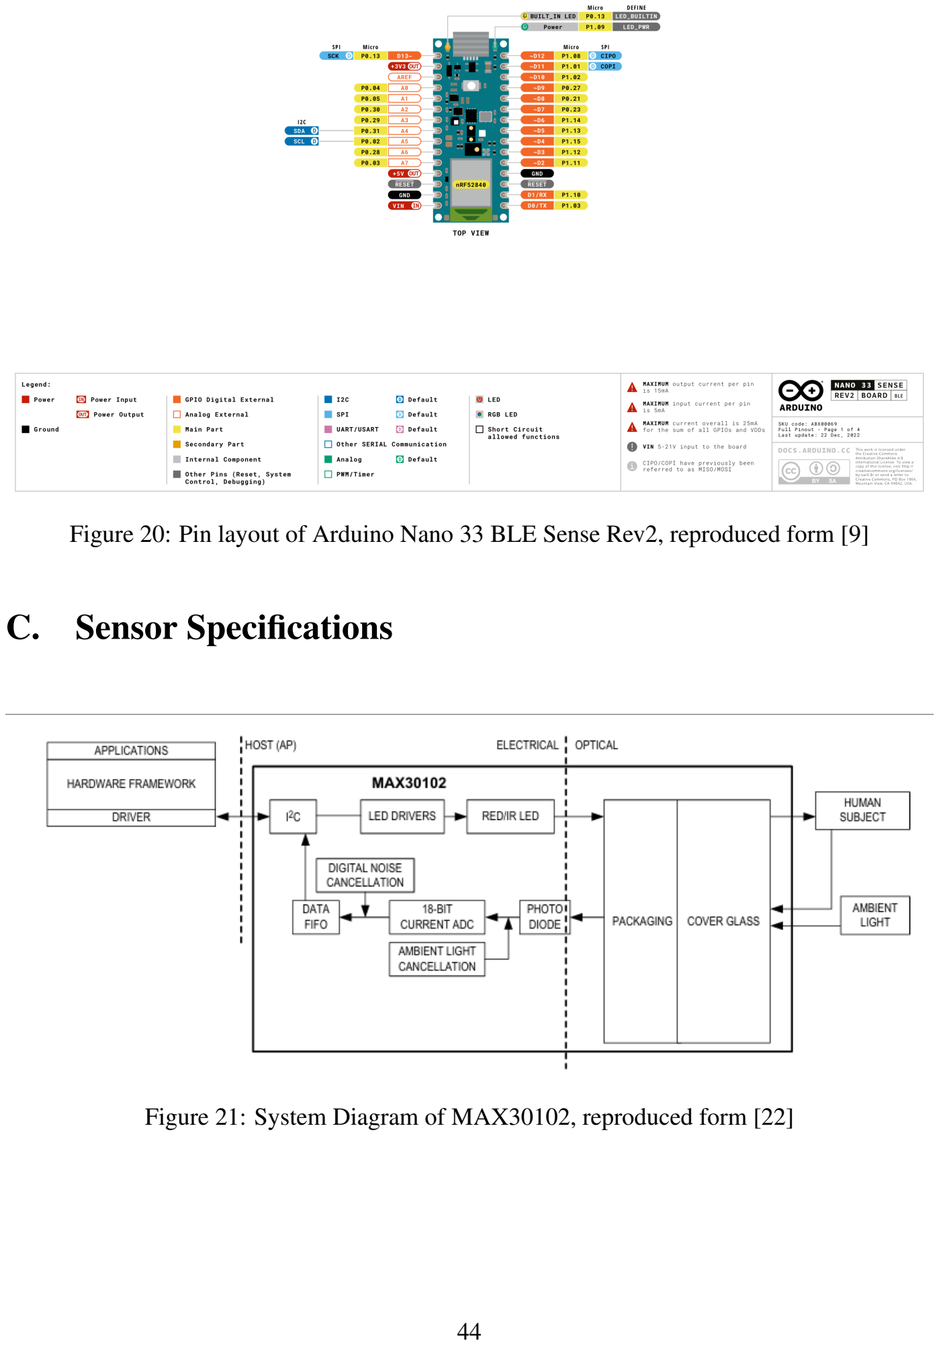
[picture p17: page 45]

Figure 20: Pin layout of Arduino Nano 33 BLE Sense Rev2, reproduced form [9]

## C. Sensor Specifications

Figure 21: System Diagram of MAX30102, reproduced form [22]

## D. Ethics Approval Forms

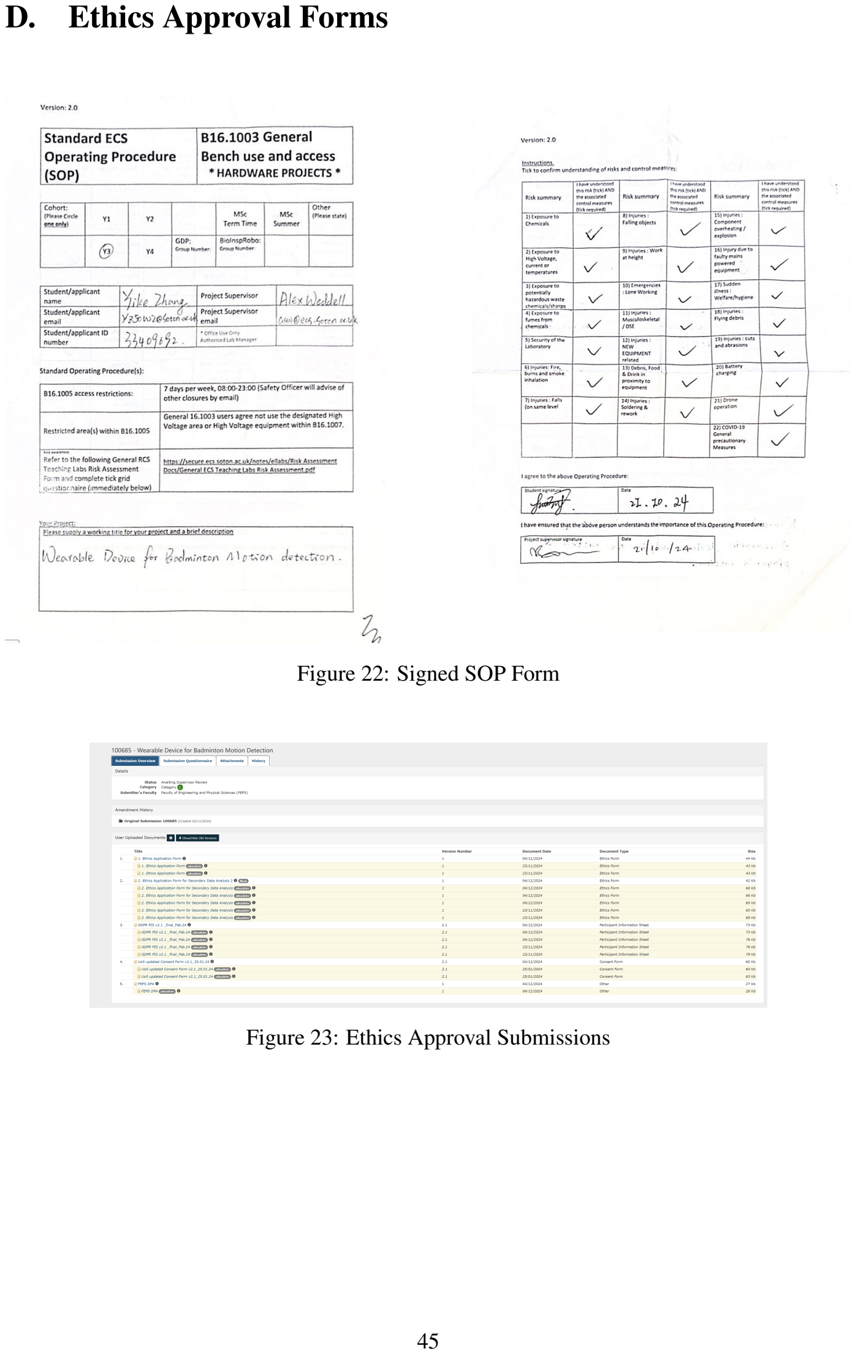
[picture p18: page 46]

Figure 22: Signed SOP Form

Figure 23: Ethics Approval Submissions

Figure 24: Ethics Application Form

## E. Code Examples

Hardware code structure:
Project Root/
libraries/
Arduino BMI270 BMM150/
ArduinoBLE/
Madgwick/
MAX3010x Sensor Library-1.0.5/ src/
Bluetooth.cpp
Bluetooth.h
Filter.cpp
Filter.h
HeartRateSpO2.cpp
HeartRateSpO2.h
main.ino

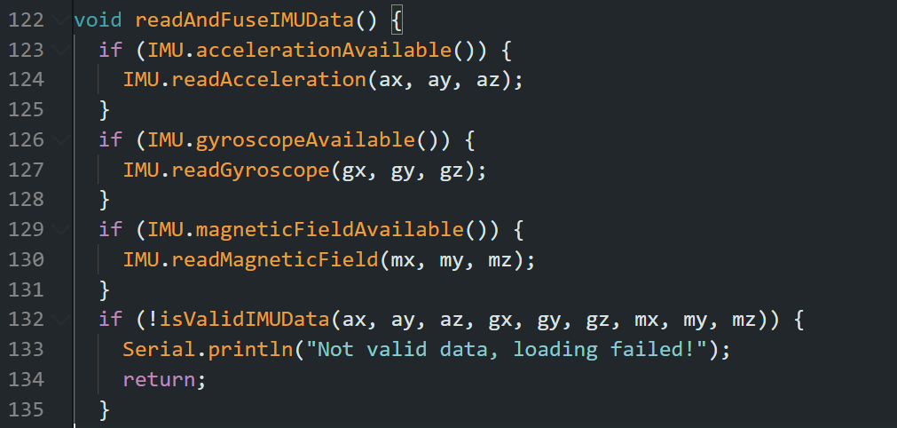
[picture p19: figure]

Figure 25: Code example of Reading Data

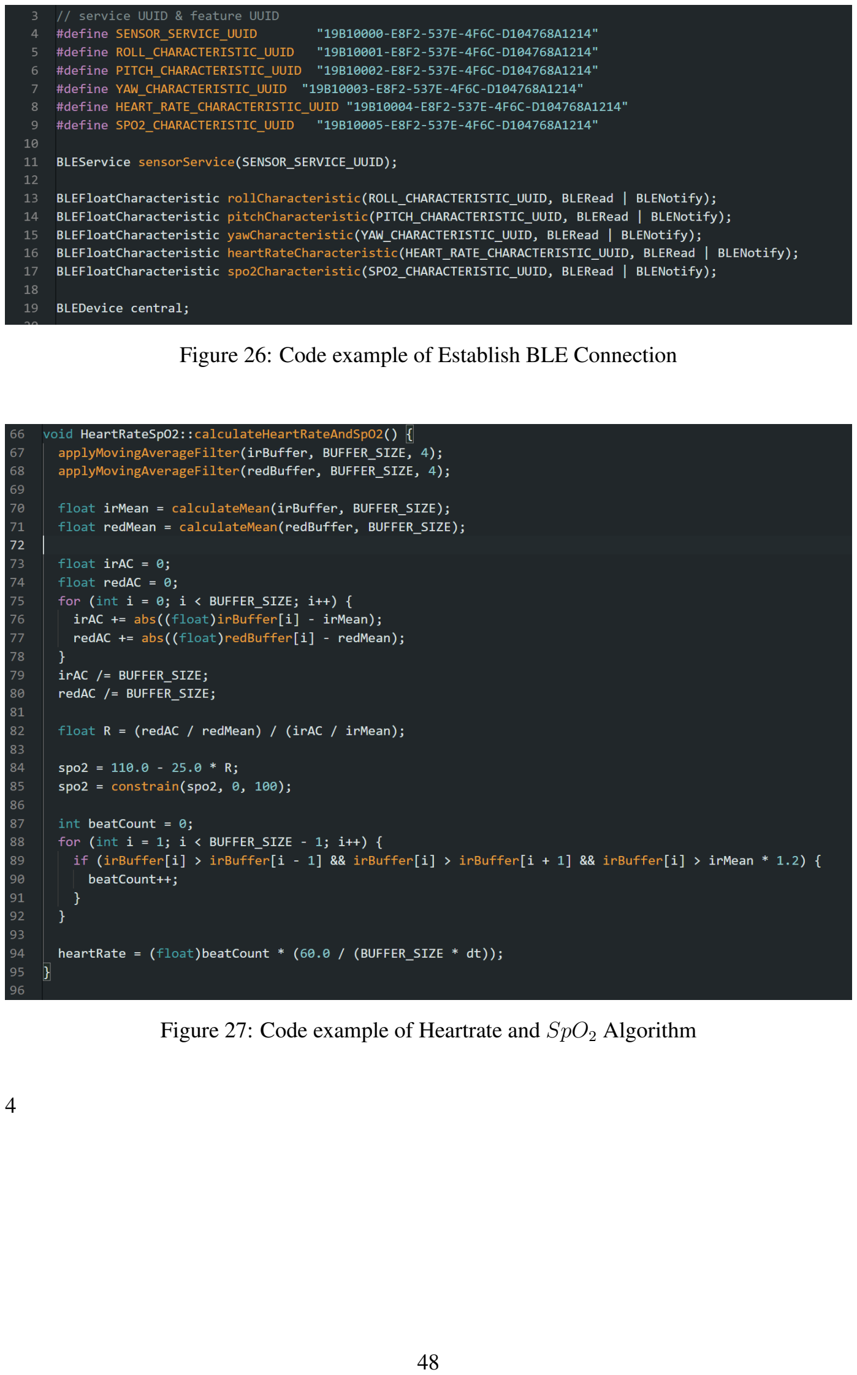
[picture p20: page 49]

Figure 26: Code example of Establish BLE Connection

Figure 27: Code example of Heartrate and SpO2 Algorithm

4

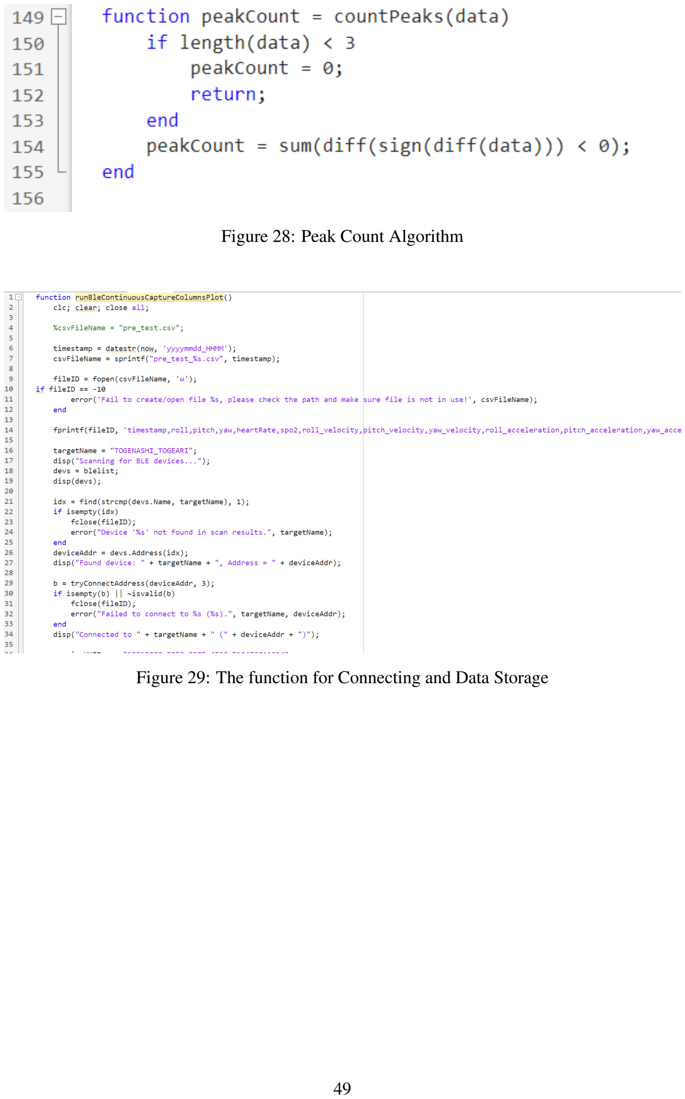
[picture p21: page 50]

Figure 28: Peak Count Algorithm

Figure 29: The function for Connecting and Data Storage

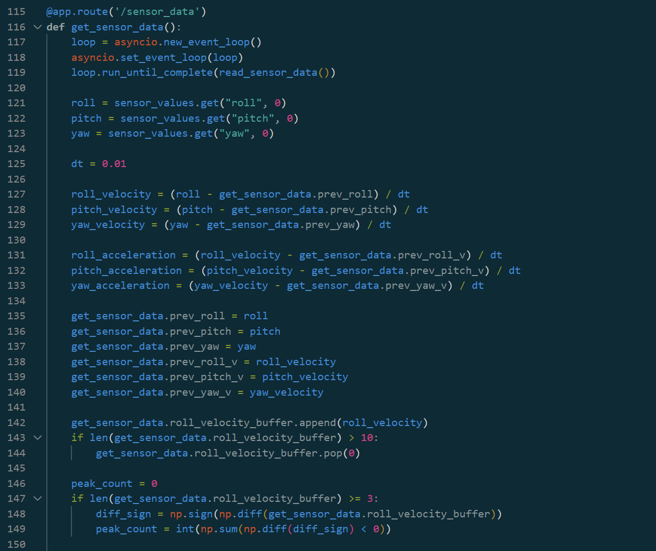
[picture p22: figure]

Figure 30: Code example of Data Processing Progress in Pyhton

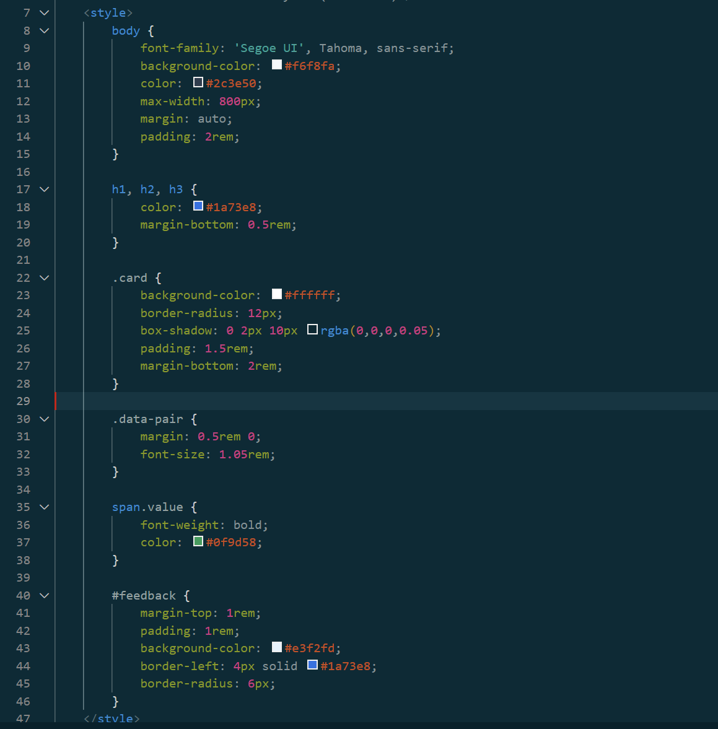
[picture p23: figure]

Figure 31: Code example of UI

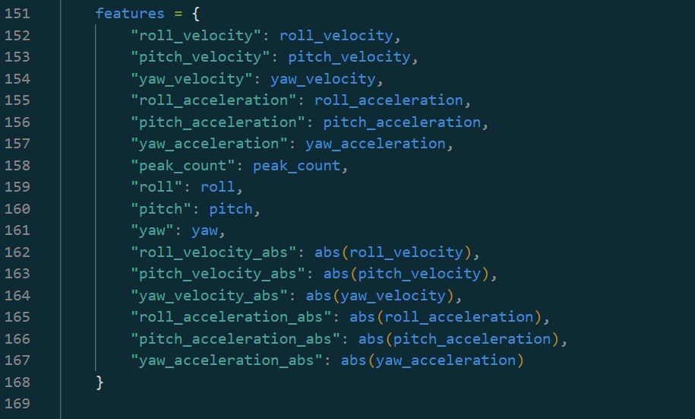
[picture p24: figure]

Figure 32: Code example of Extended 16 Features

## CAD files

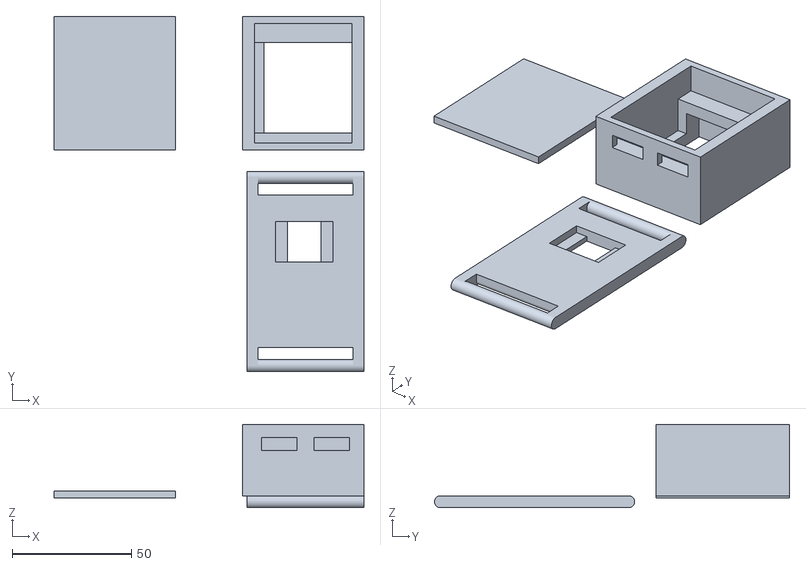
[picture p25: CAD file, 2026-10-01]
3D_Model/3D.stl
130.0 x 149.0 x 35.0

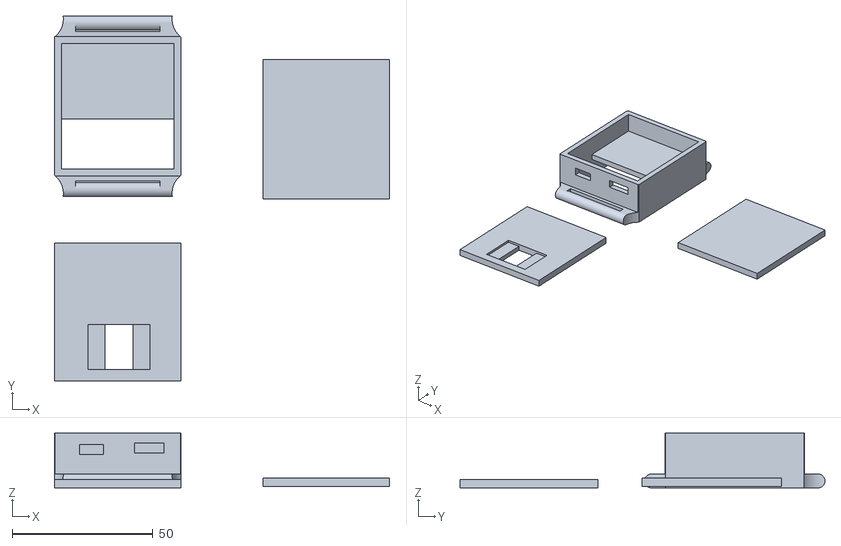
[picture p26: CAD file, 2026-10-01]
Enclosure/c1.stl
119.0 x 129.5 x 19.5

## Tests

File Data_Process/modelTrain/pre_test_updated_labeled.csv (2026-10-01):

timestamp | roll | pitch | yaw | heartRate | spo2 | roll_velocity | pitch_velocity | yaw_velocity | roll_acceleration | pitch_acceleration | yaw_acceleration | peak_count | label
0 | 0 | 0 | 0 | 0 | 0 | 0 | 0 | 0 | 0 | 0 | 0 | 0 | rest
0.1921 | 0 | 0 | 0 | 0 | 0 | 0 | 0 | 0 | 0 | 0 | 0 | 0 | rest
0.4192 | 0 | 0 | 0 | 0 | 0 | 0 | 0 | 0 | 0 | 0 | 0 | 0 | rest
0.6288 | 0 | 0 | 0 | 0 | 0 | 0 | 0 | 0 | 0 | 0 | 0 | 0 | rest
0.8369 | 0 | 0 | 0 | 0 | 0 | 0 | 0 | 0 | 0 | 0 | 0 | 0 | rest
1.2015 | 0 | 0 | 0 | 0 | 0 | 0 | 0 | 0 | 0 | 0 | 0 | 0 | rest
1.7991 | 0 | 0 | 0 | 0 | 0 | 0 | 0 | 0 | 0 | 0 | 0 | 0 | rest
2.4118 | 0 | 0 | 0 | 0 | 0 | 0 | 0 | 0 | 0 | 0 | 0 | 0 | rest
2.9988 | 0 | 0 | 0 | 0 | 0 | 0 | 0 | 0 | 0 | 0 | 0 | 0 | rest
3.5966 | 0 | 0 | 0 | 0 | 0 | 0 | 0 | 0 | 0 | 0 | 0 | 0 | rest
4.2014 | 0 | 0 | 0 | 0 | 0 | 0 | 0 | 0 | 0 | 0 | 0 | 0 | rest
4.8007 | 0 | 0 | 0 | 0 | 0 | 0 | 0 | 0 | 0 | 0 | 0 | 0 | rest
5.4007 | 0 | 0 | 0 | 0 | 0 | 0 | 0 | 0 | 0 | 0 | 0 | 0 | rest
6.0609 | 0 | 0 | 0 | 0 | 0 | 0 | 0 | 0 | 0 | 0 | 0 | 0 | rest
6.6617 | 0 | 0 | 0 | 0 | 0 | 0 | 0 | 0 | 0 | 0 | 0 | 0 | rest
7.2566 | 0 | 0 | 0 | 0 | 0 | 0 | 0 | 0 | 0 | 0 | 0 | 0 | rest
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

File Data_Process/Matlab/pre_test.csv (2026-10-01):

timestamp | roll | pitch | yaw | heartRate | spo2 | roll_velocity | pitch_velocity | yaw_velocity | roll_acceleration | pitch_acceleration | yaw_acceleration | peak_count
0.0000 | 0.0000 | 0.0000 | 0.0000 | 0.0000 | 0.0000 | 0.0000 | 0.0000 | 0.0000 | 0.0000 | 0.0000 | 0.0000 | 0
0.1950 | 0.0000 | 0.0000 | 0.0000 | 0.0000 | 0.0000 | 0.0000 | 0.0000 | 0.0000 | 0.0000 | 0.0000 | 0.0000 | 0
0.3889 | 0.0000 | 0.0000 | 0.0000 | 0.0000 | 0.0000 | 0.0000 | 0.0000 | 0.0000 | 0.0000 | 0.0000 | 0.0000 | 0
0.5854 | 0.0000 | 0.0000 | 0.0000 | 0.0000 | 0.0000 | 0.0000 | 0.0000 | 0.0000 | 0.0000 | 0.0000 | 0.0000 | 0
0.8419 | 0.0000 | 0.0000 | 0.0000 | 0.0000 | 0.0000 | 0.0000 | 0.0000 | 0.0000 | 0.0000 | 0.0000 | 0.0000 | 0
1.0826 | 0.0000 | 0.0000 | 0.0000 | 0.0000 | 0.0000 | 0.0000 | 0.0000 | 0.0000 | 0.0000 | 0.0000 | 0.0000 | 0
1.6815 | 0.4999 | 0.4999 | 0.5049 | 0.0000 | 0.0000 | 49.9868 | 49.9928 | 50.4947 | 4998.6826 | 4999.2842 | 5049.4663 | 0
2.2826 | 0.4998 | 0.4999 | 0.5077 | 0.0000 | 0.0000 | -0.0058 | -0.0033 | 0.2787 | -4999.2642 | -4999.6133 | -5021.5918 | 1
2.9410 | 0.4998 | 0.4999 | 0.5077 | 0.0000 | 0.0000 | 0.0000 | 0.0000 | 0.0000 | 0.5817 | 0.3293 | -27.8747 | 1
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

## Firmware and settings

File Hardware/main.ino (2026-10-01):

// 适度编程益脑，过度编程伤身
// 合理安排时间，享受健康生活

// Copyright (c) 2024 Yike Zhang (Arcadia_Ebendie)
// All rights reserved.

// This software is the confidential and proprietary information of Yike Zhang
// ("Confidential Information"). You shall not disclose such Confidential Information
// and shall use it only in accordance with the terms of the license agreement you entered into
// with Yike Zhang.

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
//     .::-------------------------------:---------==-=-     
//     ::-=+++++++++*+++++++++=++++=++++*+++++++++***#*##-    
//    .:-==++++=+=+**++++++++++++++-+++++*+++++******####*.   
//   .:-=+=++++++++*+++++++++++++++::++++*++++*+*****#####+   
//   ::-=++++++++++*+++++++++++++++:.=+++*++++********#####-  
//   :-=+++++++++++*+++++++++++++++:..++**************#####*  
//  .:-=++++++++++++++++*****++++++...-+++*+**+*******######: 
//  ::-+++++++++++++++++++++++++++=....++**+++++******######- 
//  ::=+++++++++++++++++*+++++++++=....=+++=+++++*****######= 
//  ::=+++++++++++++++++++++++++++-....:+++-++++=+*****#####+ 
//  ::+++++++++++++++++*++++++++++:.....+++.++++-+*****#####+ 
//  ::++++++++++++++++++++++*+++++......=+*.=***+******#####+ 
//  ::=++++++++++++++++++++++*+++=......-*#*###**%#****#####- 
//  .:=+++++++++++++*##########*+-......=+%%***=:+#%#**#####. 
//  .:-++++++++++++##*+*++++**+*+:........=%%#*#. .--*#####:  
//   :-+++++++++++##++==+##+#*++=........-*#%#:+. ..-######   
//   ::++++++++++++*++=#+#%+-*............-:-::: ...=######   
//   :-++*++++++++++-:.+:::.:: ............:........*######=  
//  :-++*++*+++++++=.. .:..........................-########+ 
//  -=++*++******++=...............................+######### 
//  =+++*++*+*******:.............................-########## 
//  ++++*++*+++++***:............................-+########## 
//  ++++**+*+++++*++-...........................::-#########* 
//  *+=+**+***+++*+++=...........................-*######%##- 
//  *%==+**********+***:.......................:+###**##%@%@+ 
//  -%%=-+*+**+*********+-...................:+###***#%@@@@@+ 
//  +*%@#+=++++++**********=:..............:+###%%%@@@@@@@@@+ 
//  *@@@@@%-=+++++#++=+**#*#**::.........-*#%%%@@@@@@@@@@@@@= 
//  *@@@@@@--+++++*++=-=*%##***::::::..:---+%%%%@@@@@@@@@@@@= 

#include "Arduino_BMI270_BMM150.h" 
#include "Wire.h"                   
#include "Filter.h"                 
#include "Bluetooth.h"

#include "MadgwickAHRS.h"

#include "MAX30102.h"

#include "HeartRateSpO2.h"

// MAX30102
MAX30102 particleSensor;

//不嘻嘻
HeartRateSpO2 hrSpO2Calculator;

Madgwick filter;

float ax, ay, az; // 加速度计
float gx, gy, gz; // 陀螺仪
float mx, my, mz; // 磁力计

float roll = 0, pitch = 0, yaw = 0;

float dt = 0.005;    // s^(-1)
float alpha = 0.98; // 权重参数，测试后调整

// float rollAlpha = 0.1;
// float pitchAlpha = 0.3;
// float yawAlpha = 0.5; //权重参数，测试后根据实际情况调整！！！
// //如果三种姿态函数使用不一样的alpha

// long irValue, redValue;
float heartRate = 0;
float spo2 = 0;

void i2cScanner() {
  Serial.println("Scanning for I2C devices...");
  byte count = 0;
  for (byte i = 1; i < 127; i++) {
    Wire.beginTransmission(i);
    if (Wire.endTransmission() == 0) {
      Serial.print("Found I2C Device at 0x");
      if (i < 16) Serial.print("0");
      Serial.print(i, HEX);
      Serial.println(" !");
      count++;
      delay(1);
    }
  }
  if (count == 0) {
    Serial.println("No I2C devices found.");
  } else {
    Serial.print("Found ");
    Serial.print(count);
    Serial.println(" device(s).");
  }
}

void readAndFuseIMUData() {
  if (IMU.accelerationAvailable()) {
    IMU.readAcceleration(ax, ay, az);
  } 
  if (IMU.gyroscopeAvailable()) {
    IMU.readGyroscope(gx, gy, gz);
  }
  if (IMU.magneticFieldAvailable()) {
    IMU.readMagneticField(mx, my, mz);
  }
  if (!isValidIMUData(ax, ay, az, gx, gy, gz, mx, my, mz)) {
    Serial.println("Not valid data, loading failed!");
    return;
  }


  float accThreshold = 1.0;
  if (abs(ax) < accThreshold && abs(ay) < accThreshold && abs(az) < accThreshold) {
    return;
  }

  float gyroThreshold = 0.1;
  if (abs(gx) < gyroThreshold && abs(gy) < gyroThreshold && abs(gz) < gyroThreshold) {
  return;
  }


  imuLowPassFilter(ax, ay, az, gx, gy, gz, mx, my, mz); //LPF

  float rollAcc = atan2(ay_filtered, az_filtered) * 180 / PI;
  float pitchAcc = atan(-ax_filtered / sqrt(ay_filtered * ay_filtered + az_filtered * az_filtered)) * 180 / PI;

  static float rollGyro = 0;
  static float pitchGyro = 0;
  static float yawGyro = 0;

  rollGyro += gx_filtered * dt;
  pitchGyro += gy_filtered * dt;
  yawGyro += gz_filtered *dt;

  roll = alpha * (roll + gx_filtered * dt) + (1 - alpha) * rollAcc;
  pitch = alpha * (pitch + gy_filtered * dt) + (1 - alpha) * pitchAcc;

  float yawMag = atan2(my_filtered, mx_filtered) * 180 / PI;
  
  yaw = alpha * (yaw + gz_filtered * dt) + (1 - alpha) * yawMag;

  normalizeIMUData(roll, pitch, yaw);
}

void setup() {

  filter.begin(200);

  Serial.begin(115200);

  initFilter();

  unsigned long startTime = millis();

  while (!Serial) {
    if (millis() - startTime > 3000) {
      break;
    }
  }

  Serial.println("Serial communication initialized");

  if (!IMU.begin()) {
    Serial.println("Failed to initialize IMU!");
    // while (1);
    delay(2000);
    Serial.println("IMU time out! Continue without IMU...");
  }
  else{
    Serial.println("IMU initialized");
  }

  Wire.begin();

  delay(1000);

  i2cScanner();

  if (!particleSensor.begin()) {
    Serial.println("MAX30102 not found!");
    // while (1);
    delay(2000);
    Serial.println("MAX30102 time out! Continue without MAX30102...");
  }
  else{
    Serial.println("MAX30102 initialized!");
  }

  particleSensor.setMode(MAX30102::MODE_SPO2); // SPO2 模式
  particleSensor.setADCRange(MAX30102::ADC_RANGE_16384NA); // ADC 范围
  particleSensor.setSamplingRate(MAX30102::SAMPLING_RATE_200SPS); // 采样率 100Hz
  particleSensor.setResolution(MAX30102::RESOLUTION_18BIT_4110US); // 分辨率 脉冲宽度
  particleSensor.setLedCurrent(MAX30102::LED_RED, 60); // 红光 LED 电流（0-255，对应 0-51mA，每步 0.2mA）
  particleSensor.setLedCurrent(MAX30102::LED_IR, 60); // 红外光 LED 电流

  hrSpO2Calculator.begin(particleSensor, 100.0);

  initBLE();
}

void loop() {
  pollBLE();
  BLE.poll();
  if (central && central.connected()) {
    readAndFuseIMUData();

    bool newData = hrSpO2Calculator.update();

    heartRate = hrSpO2Calculator.getHeartRate();
    spo2 = hrSpO2Calculator.getSpO2();

    updateBLECharacteristics(roll_normalized, pitch_normalized, yaw_normalized, heartRate, spo2);
    printSensorData();
  }
  delay(dt * 100);
}

void printSensorData() {

  // Serial.print("加速度计 (ax, ay, az): ");
  // Serial.print(ax, 6); Serial.print(", ");
  // Serial.print(ay, 6); Serial.print(", ");
  // Serial.println(az, 6);
  // Serial.println("---------------------------");

  // Serial.print("陀螺仪 (gx, gy, gz): ");
  // Serial.print(gx, 6); Serial.print(", ");
  // Serial.print(gy, 6); Serial.print(", ");
  // Serial.println(gz, 6);
  // Serial.println("---------------------------");

  // Serial.print("磁力计 (mx, my, mz): ");
  // Serial.print(mx, 6); Serial.print(", ");
  // Serial.print(my, 6); Serial.print(", ");
  // Serial.println(mz, 6);
  // Serial.println("---------------------------");

  Serial.print("Normalised Roll=");
  Serial.print(roll_normalized, 4);
  Serial.print(", Normalised Pitch=");
  Serial.println(pitch_normalized, 4);
  Serial.print(", Normalised Yaw=");
  Serial.println(yaw_normalized, 4);
  Serial.println("---------------------------");

   Serial.print("Heartbeat (bpm): ");
   Serial.println(heartRate, 2);
   Serial.print(", SpO2 (%): ");
   Serial.println(spo2, 2);

  Serial.println("---------------------------");
  // Serial.println("Copyright: Arcadia_Ebendie / Yike Zhang");
  // Serial.println("---------------------------");

}

// void printSensorData() {
//   Serial.print(roll_normalized, 4);
//   Serial.print(" ");
//   Serial.print(pitch_normalized, 4);
//   Serial.print(" ");
//   Serial.println(yaw_normalized, 4); 
// }

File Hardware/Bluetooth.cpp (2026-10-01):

#include "Bluetooth.h"

// service UUID & feature UUID
#define SENSOR_SERVICE_UUID        "19B10000-E8F2-537E-4F6C-D104768A1214"       
#define ROLL_CHARACTERISTIC_UUID   "19B10001-E8F2-537E-4F6C-D104768A1214"      
#define PITCH_CHARACTERISTIC_UUID  "19B10002-E8F2-537E-4F6C-D104768A1214"
#define YAW_CHARACTERISTIC_UUID  "19B10003-E8F2-537E-4F6C-D104768A1214"
#define HEART_RATE_CHARACTERISTIC_UUID "19B10004-E8F2-537E-4F6C-D104768A1214"
#define SPO2_CHARACTERISTIC_UUID   "19B10005-E8F2-537E-4F6C-D104768A1214"

BLEService sensorService(SENSOR_SERVICE_UUID);

BLEFloatCharacteristic rollCharacteristic(ROLL_CHARACTERISTIC_UUID, BLERead | BLENotify);
BLEFloatCharacteristic pitchCharacteristic(PITCH_CHARACTERISTIC_UUID, BLERead | BLENotify);
BLEFloatCharacteristic yawCharacteristic(YAW_CHARACTERISTIC_UUID, BLERead | BLENotify);
BLEFloatCharacteristic heartRateCharacteristic(HEART_RATE_CHARACTERISTIC_UUID, BLERead | BLENotify);
BLEFloatCharacteristic spo2Characteristic(SPO2_CHARACTERISTIC_UUID, BLERead | BLENotify);

BLEDevice central;

// BLE initialization
void initBLE() {
  if (!BLE.begin()) {
    Serial.println("BLE initialization failed");
    while (1);
  }
  Serial.println("BLE initialization succeed");
  

  BLE.setDeviceName("TOGENASHI_TOGEARI");
  BLE.setLocalName("TOGENASHI_TOGEARI");
  BLE.setAdvertisedService(sensorService); 

  sensorService.addCharacteristic(rollCharacteristic);
  sensorService.addCharacteristic(pitchCharacteristic);
  sensorService.addCharacteristic(yawCharacteristic);
  sensorService.addCharacteristic(heartRateCharacteristic);
  sensorService.addCharacteristic(spo2Characteristic);

  BLE.addService(sensorService);

  rollCharacteristic.writeValue(0.0);
  pitchCharacteristic.writeValue(0.0);
  yawCharacteristic.writeValue(0.0);
  heartRateCharacteristic.writeValue(0.0);
  spo2Characteristic.writeValue(0.0);

  BLE.advertise();
  Serial.println("BLE established, waiting for connection...");
}

void updateBLECharacteristics(float roll, float pitch, float yaw, float heartRate, float spo2) {
  rollCharacteristic.writeValue(roll);
  pitchCharacteristic.writeValue(pitch);
  yawCharacteristic.writeValue(yaw);
  heartRateCharacteristic.writeValue(heartRate);
  spo2Characteristic.writeValue(spo2);
}

void pollBLE() {
  //FBI watching!
  BLEDevice newCentral = BLE.central();

  if (newCentral && !central) {
    central = newCentral;
    Serial.print("Device Connected: ");
    Serial.println(central.address());
  }

  if (central && !central.connected()) {
    Serial.print("Device Disconnected: ");
    Serial.println(central.address());
    central = BLEDevice(); // 这里进行了修改，原本是 central = 0
  }

  BLE.poll();
}
